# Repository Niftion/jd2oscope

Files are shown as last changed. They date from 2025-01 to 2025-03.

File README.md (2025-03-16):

## Project Status

- `3dmodels/`: Iteration 1 complete; iteration 2 WIP
  - Considering different potentiometer & button models (pot.s too small for knobs)
  - Looking into overhead enclosure for button/knob interface (i.e., transitioning from partially exposed to fully enclosed)
- `firmware/`: Iteration 1 WIP
  - Currently troubleshooting issues with SPI comm.; assumed resolution w/ the inclusion of tri-state buffer
  - Potentiometers laggy; assumed resolution w/ swap for rotary encoders
- `hardware/`: Iteration 1 complete; iteration 2 WIP
  - Adjustments needed to account for pullups/pulldowns & tri-state buffer
  - Considering swapping potentiometers for rotary encoders & using different buttons
  - Potentially re-evaluate netclasses/copper trace thicknesses
  - Flip around opAmp (for some reason was inverted in schematics)
  - Ensure all passives' values *actually exist* (if not, modify circuit to use ones that do)
  - Swap 5V LDO to buck converter (& generally re-evaluate power distribution method (currently not adequate for long-term usage))

## Project Leads

- `3dmodels/`: [@kaylauyema](https://github.com/kaylauyema)
  - *See [Onshape](https://cad.onshape.com/documents/8ccdb21e8d1079c729b3d0f6/w/fb9eb84c8df37a115b39a8e3/e/654db45d68c6c467c0a4227c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) for all CAD files*
- `firmware/`: [@StPelican42](https://github.com/StPelican42)
- `hardware/`: [@Niftion](https://github.com/Niftion)

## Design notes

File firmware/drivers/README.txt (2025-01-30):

ESP32 Windows Driver (may have different names),
 - Plug in ESP32 via cable
 - Go to Device Manager
 - Expand Ports and open properties of the device USB to UART Bridge
 - Click the Driver tab and update driver with the CP210x_Universal_Windows_Driver folder

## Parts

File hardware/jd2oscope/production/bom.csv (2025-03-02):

Designator | Footprint | Quantity | Value | LCSC Part #
C1, C10, C11, C12, C13, C14, C16, C17, C18, C19, C2, C3, C4, C6, C8 | 0603 | 15 | 0.1u
C15, C9 | 0603 | 2 | 2.7n
C5, C7 | 0603 | 2 | 10u
D1 | D_SOD-123 | 1 | SS14 | SS14
D2 | 0805 | 1 | LTST-C170CKT | LTST-C170KFKT
J1 | TerminalBlock_RND_205-00001_1x02_P5.00mm_Horizontal | 1 | 9V_CONN
J2, J3 | LINX_CONBNC001 | 2 | CONBNC001
R1 | 0603 | 1 | 100
R10, R11, R12, R13, R14, R15, R3, R4, R5, R6, R7, R8 | 0603 | 12 | 1k
R16, R9 | 0603 | 2 | 117
R2 | 0603 | 1 | 560
S1 | SW_JS202011SCQN | 1 | JS202011SCQN
S2, S3, S4 | SW_KMR731NGLFS | 3 | KMR731NGLFS
U1 | MODULE_ESP32-DEVKITC-32D | 1 | ESP32-DEVKITC-32D
U2 | PinHeader_1x14_P2.54mm_Vertical | 1 | ILI9341-320x240-TFT-Touch
U3 | SOT-223-3_TabPin2 | 1 | NCP1117-5.0_SOT223
U4, U6 | SOT95P280X145-5N | 2 | OPA192IDBVR
U5, U7 | LFCSP-16-1EP_4x4mm_P0.65mm_EP2.6x2.6mm | 2 | ADS7279IPW
VR1, VR2, VR3, VR4, VR5, VR6 | TRIM_3362P-1-103LF | 6 | 3362P-1-103LF

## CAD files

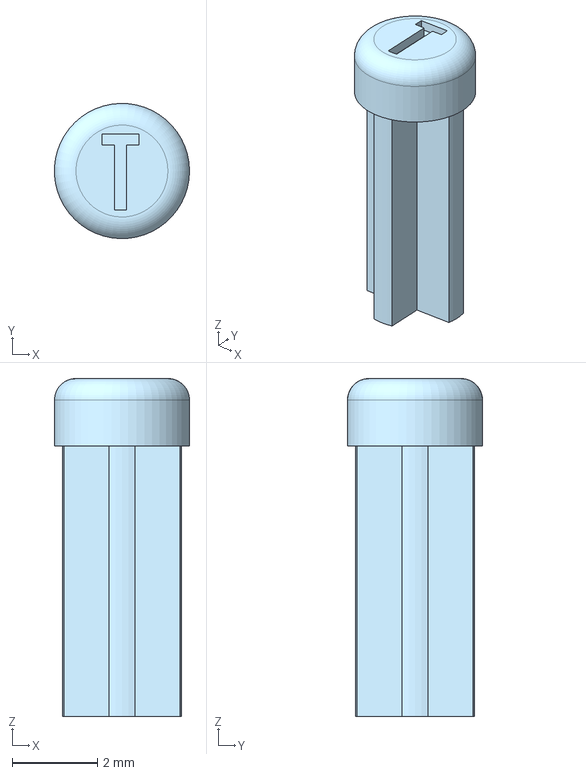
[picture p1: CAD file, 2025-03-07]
3dmodels/PotKnob_T-3x.step
3.17 x 3.17 x 7.94 mm

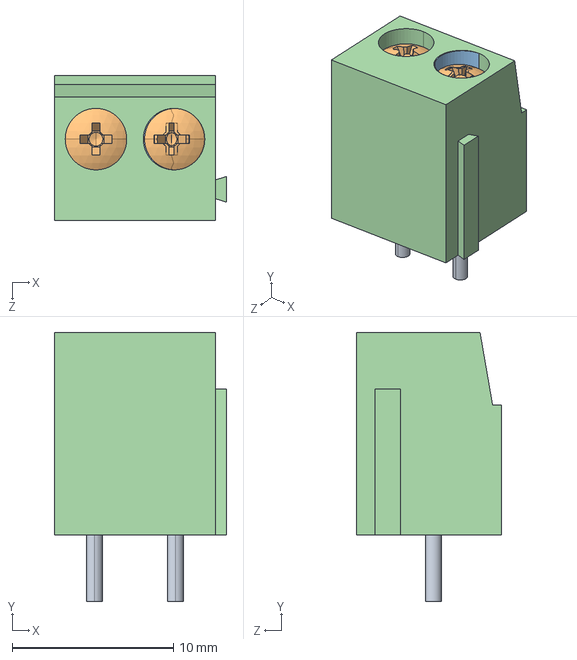
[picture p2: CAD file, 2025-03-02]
hardware/3dModels/RND 205-00001--3DModel-STEP-269445.STEP
10.7 x 16.7 x 9.02 mm

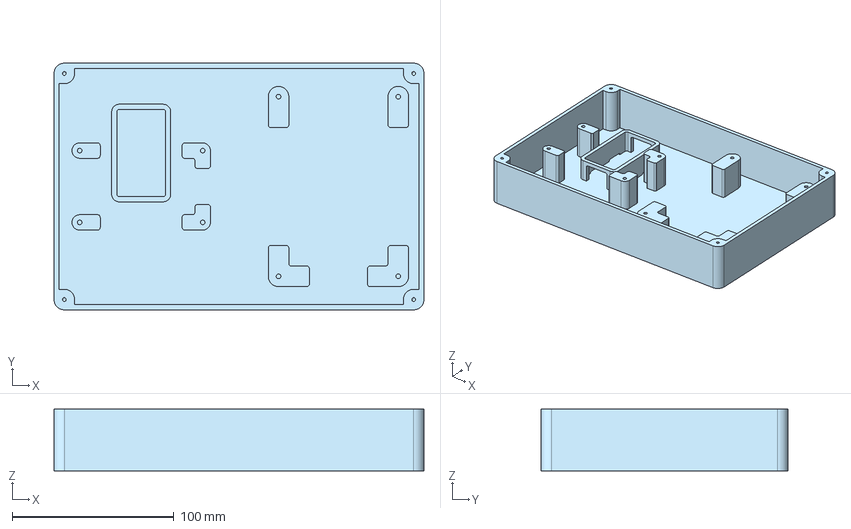
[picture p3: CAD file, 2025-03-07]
3dmodels/enclosure_bottom.step
228.6 x 152.4 x 38.1 mm

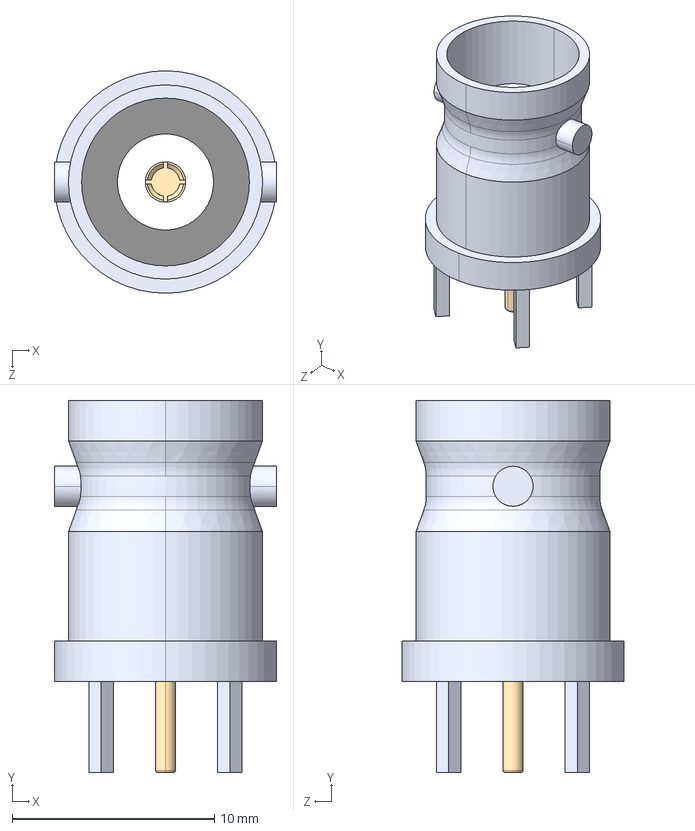
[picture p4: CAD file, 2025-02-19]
hardware/3dModels/CONBNC001.step
11.0 x 18.4 x 11.0 mm

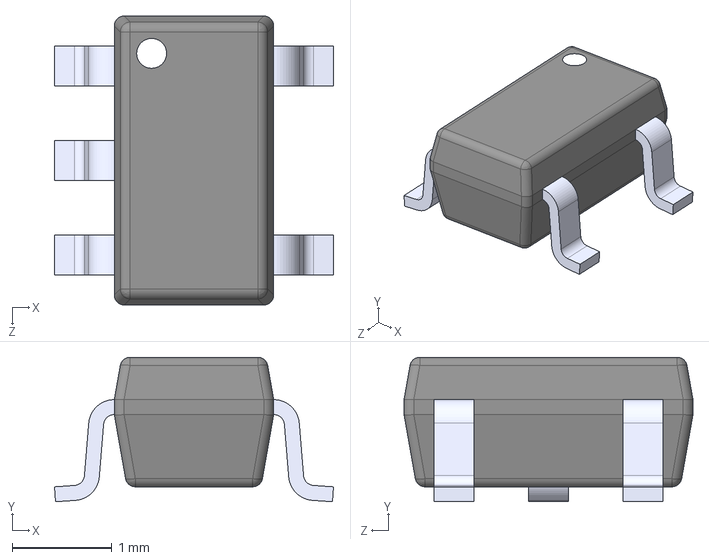
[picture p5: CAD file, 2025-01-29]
hardware/3dModels/OPA192IDBVR.STEP
2.80 x 1.45 x 2.90 mm

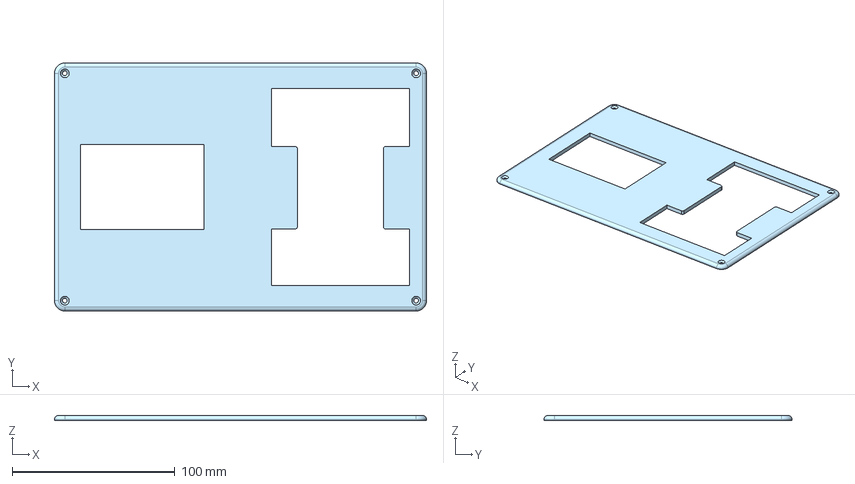
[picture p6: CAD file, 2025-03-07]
3dmodels/enclosure_top.step
228.6 x 152.4 x 3.18 mm

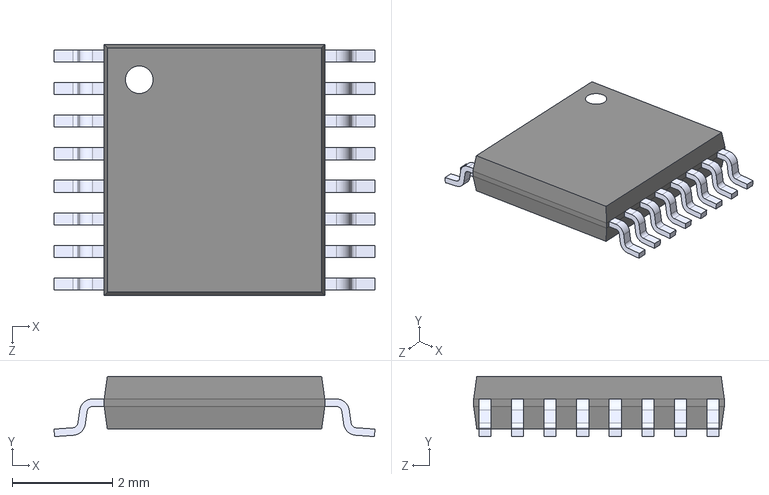
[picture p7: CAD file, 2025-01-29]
hardware/3dModels/ADS7279IPW.STEP
6.40 x 1.20 x 5.00 mm

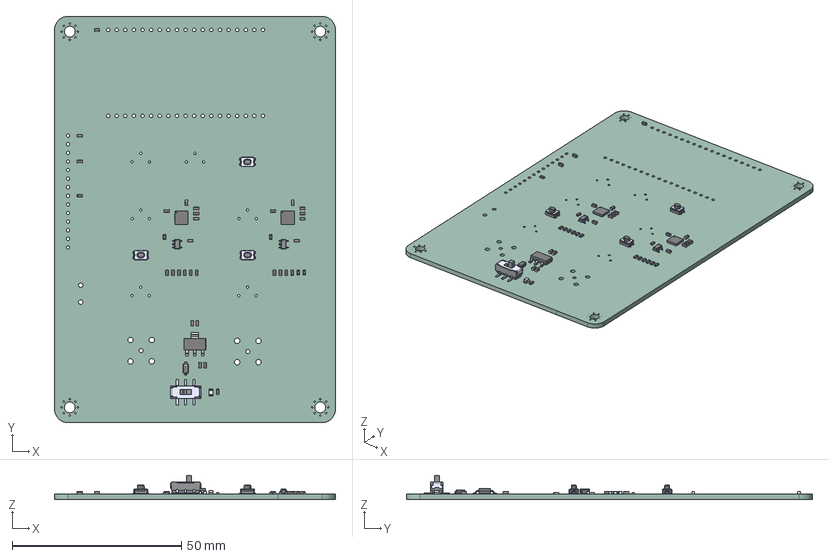
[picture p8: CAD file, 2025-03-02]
3dmodels/PCB_onlySMDs-noTracks.step
83.0 x 120.0 x 7.16 mm
R_0603_1608Metric x 16
C_0603_1608Metric x 19
CQ assembly x 2
D_SOD_123
LED_0805_2012Metric
JS202011SCQN
SOT_223
KMR731NGLFS x 3
DBV5 x 2
jd2oscope_PCB

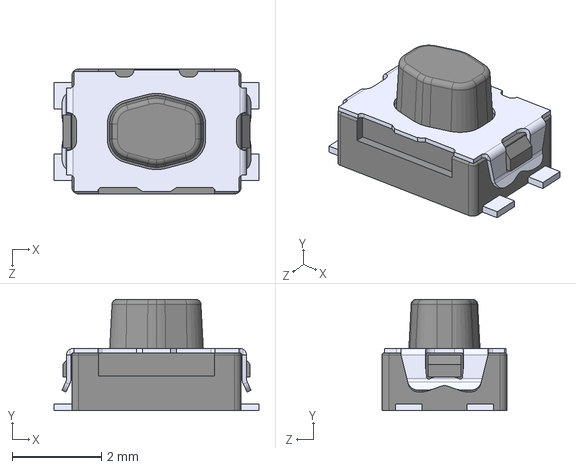
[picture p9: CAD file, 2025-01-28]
hardware/3dModels/KMR731NGLFS.step
4.60 x 2.50 x 2.80 mm

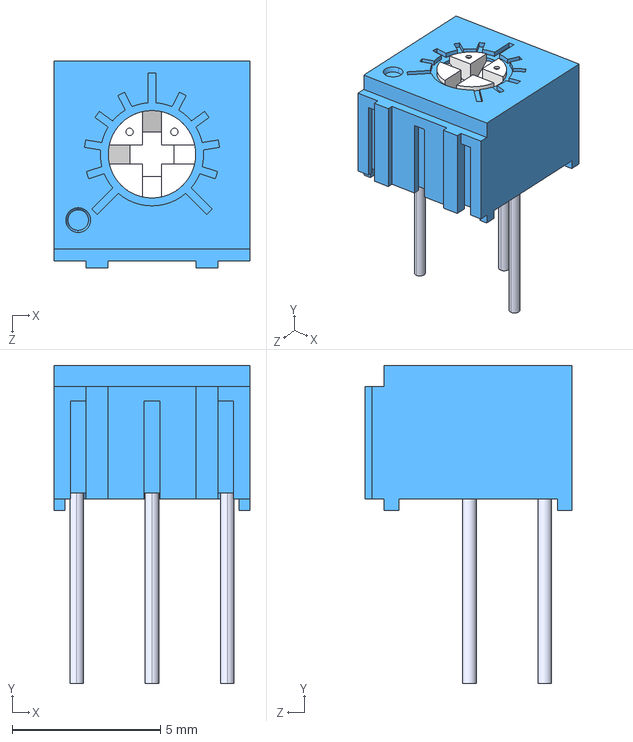
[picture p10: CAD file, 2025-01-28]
hardware/3dModels/3362P-1-103LF.step
6.60 x 10.7 x 6.99 mm

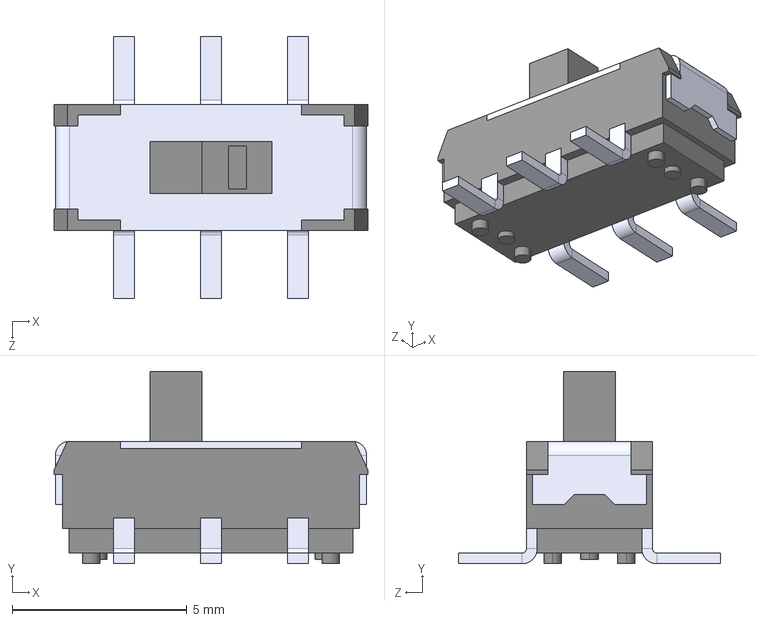
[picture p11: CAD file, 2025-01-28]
hardware/3dModels/JS202011SCQN.step
8.99 x 5.51 x 7.49 mm

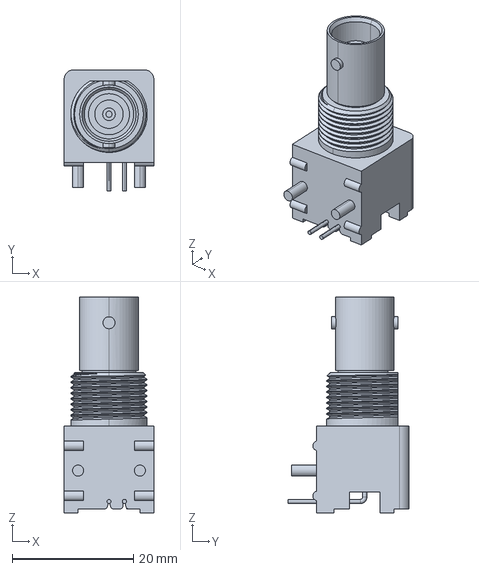
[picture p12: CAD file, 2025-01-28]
hardware/3dModels/5227161-2.step
14.8 x 20.0 x 35.6 mm

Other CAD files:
3dmodels/PotKnob_V-3x.step

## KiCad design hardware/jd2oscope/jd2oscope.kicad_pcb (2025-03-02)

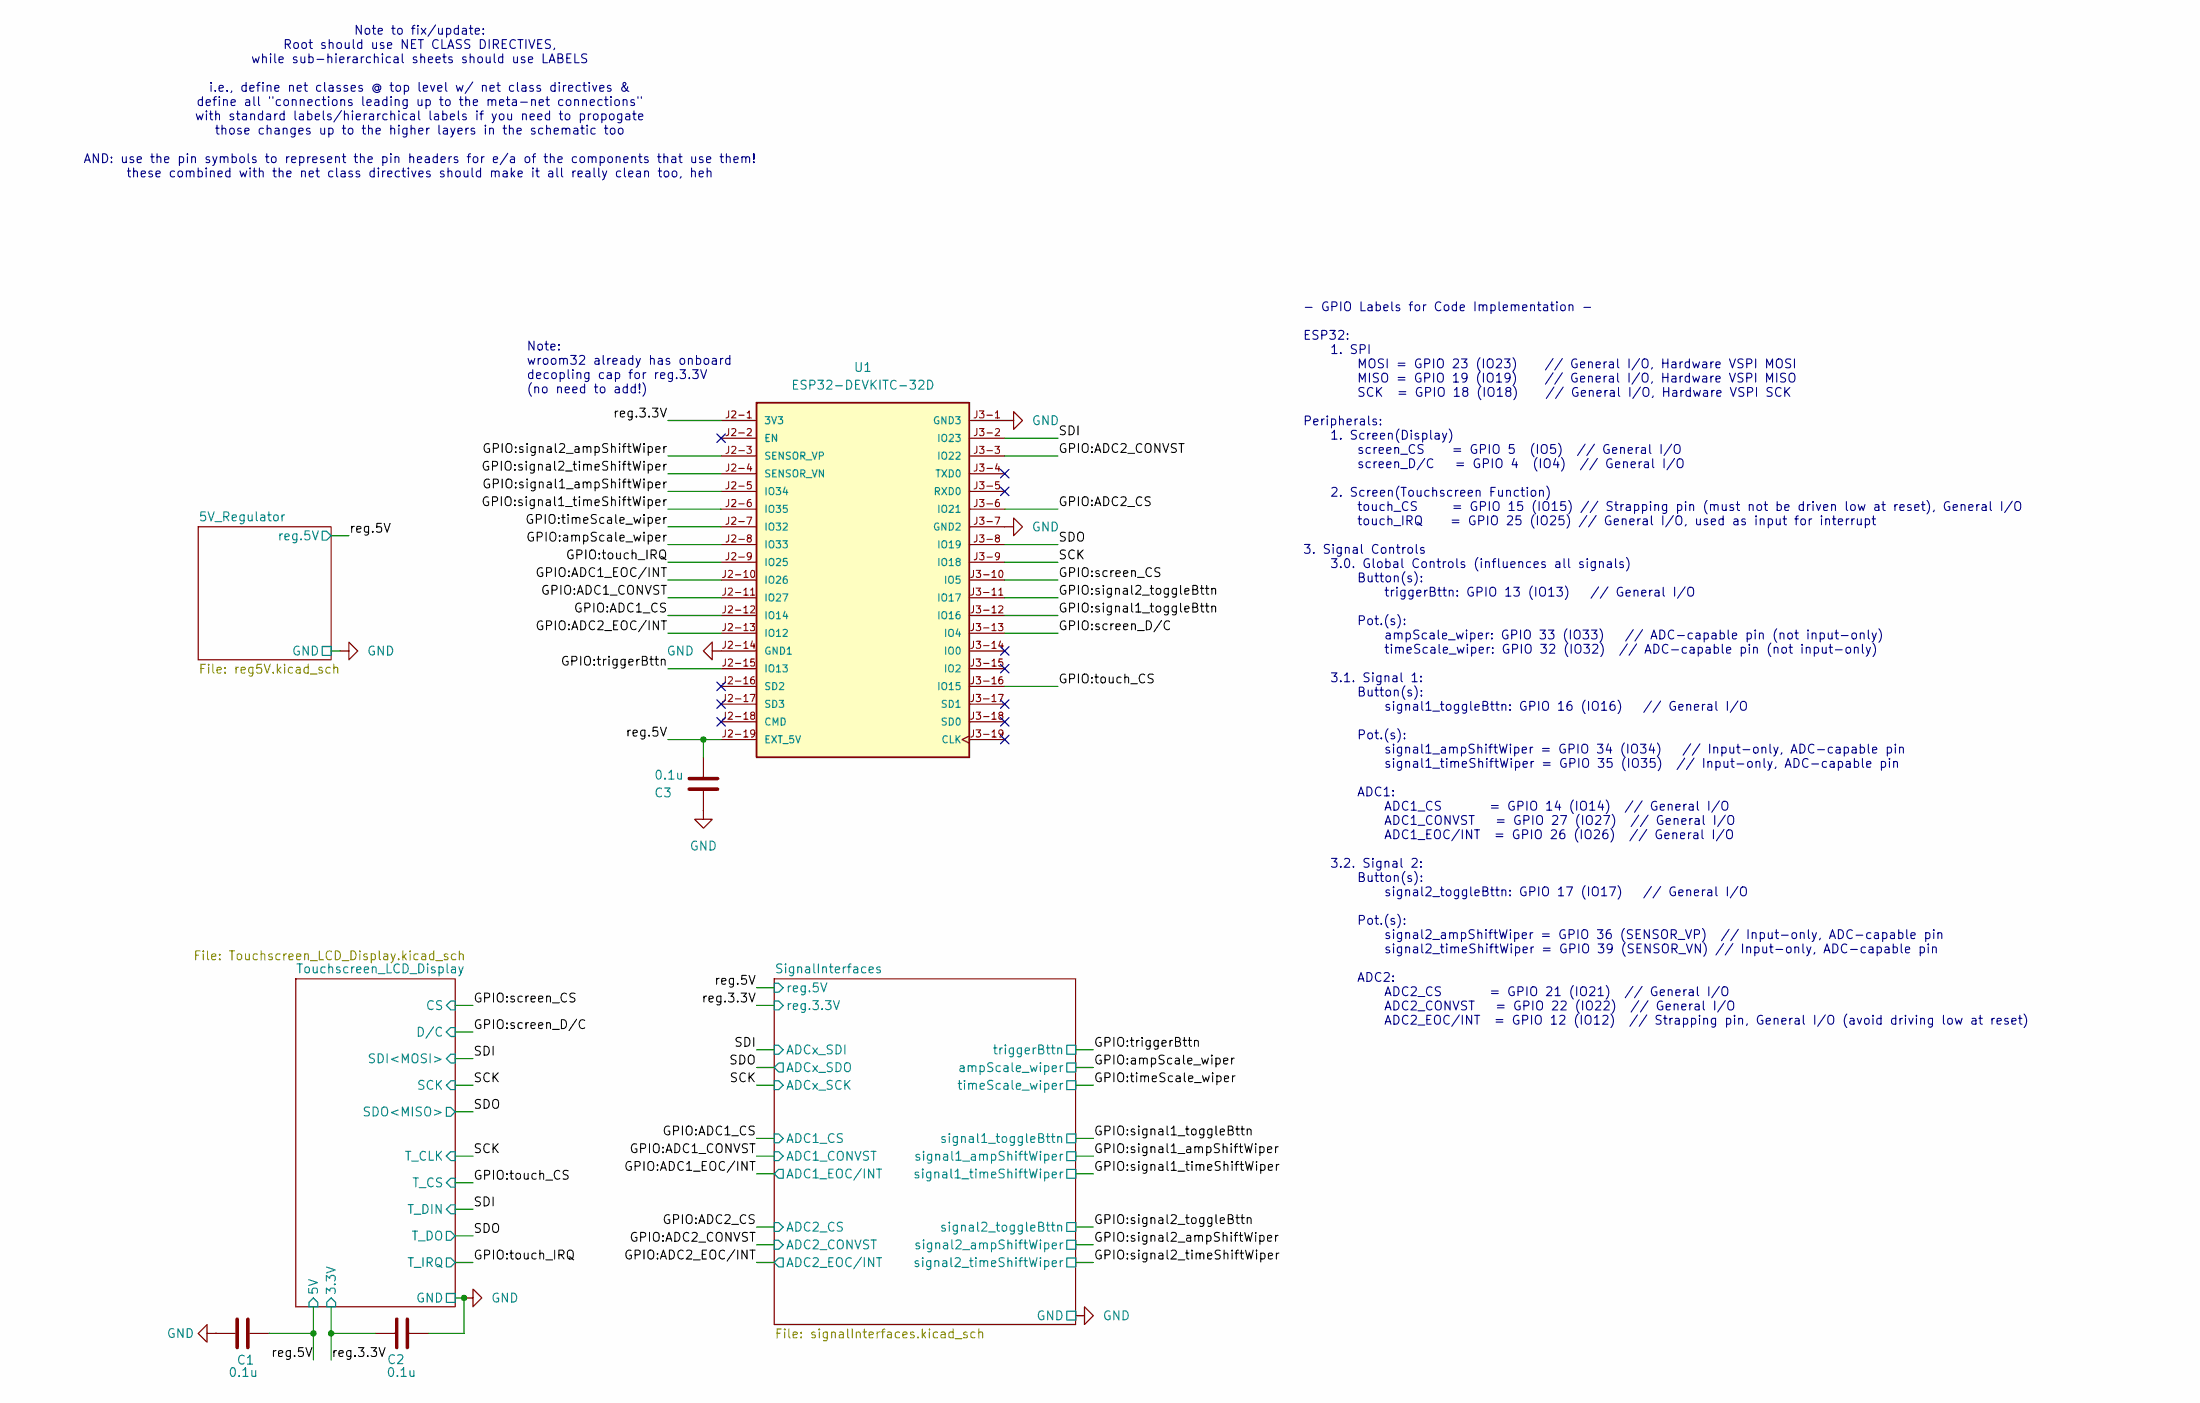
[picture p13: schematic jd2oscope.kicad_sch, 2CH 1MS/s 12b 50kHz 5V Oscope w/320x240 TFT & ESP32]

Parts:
C1, C2, C3: 0.1u; C_0603_1608Metric_Pad1.08x0.95mm_HandSolder
U1: ESP32-DEVKITC-32D; MODULE_ESP32-DEVKITC-32D; PARTREV V4; DigiKey_Part_Number 4166-ESP32-DEVKITC-32D-ND

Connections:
/GPIO:ADC1_CONVST: U1.J2-11 (IO27); also elsewhere on the board
/GPIO:ADC1_CS: U1.J2-12 (IO14); also elsewhere on the board
/GPIO:ADC1_EOC/INT: U1.J2-10 (IO26); also elsewhere on the board
/GPIO:ADC2_CONVST: U1.J3-3 (IO22); also elsewhere on the board
/GPIO:ADC2_CS: U1.J3-6 (IO21); also elsewhere on the board
/GPIO:ADC2_EOC/INT: U1.J2-13 (IO12); also elsewhere on the board
/GPIO:ampScale_wiper: U1.J2-8 (IO33); also elsewhere on the board
/GPIO:screen_CS: U1.J3-10 (IO5); also elsewhere on the board
/GPIO:screen_D/C: U1.J3-13 (IO4); also elsewhere on the board
/GPIO:signal1_ampShiftWiper: U1.J2-5 (IO34); also elsewhere on the board
/GPIO:signal1_timeShiftWiper: U1.J2-6 (IO35); also elsewhere on the board
/GPIO:signal1_toggleBttn: U1.J3-12 (IO16); also elsewhere on the board
/GPIO:signal2_ampShiftWiper: U1.J2-3 (SENSOR_VP); also elsewhere on the board
/GPIO:signal2_timeShiftWiper: U1.J2-4 (SENSOR_VN); also elsewhere on the board
/GPIO:signal2_toggleBttn: U1.J3-11 (IO17); also elsewhere on the board
/GPIO:timeScale_wiper: U1.J2-7 (IO32); also elsewhere on the board
/GPIO:touch_CS: U1.J3-16 (IO15); also elsewhere on the board
/GPIO:touch_IRQ: U1.J2-9 (IO25); also elsewhere on the board
/GPIO:triggerBttn: U1.J2-15 (IO13); also elsewhere on the board
/SCK: U1.J3-9 (IO18); also elsewhere on the board
/SDI: U1.J3-2 (IO23); also elsewhere on the board
/SDO: U1.J3-8 (IO19); also elsewhere on the board
/reg.3.3V: C2.2, U1.J2-1 (3V3); also elsewhere on the board
/reg.5V: C1.2, C3.2, U1.J2-19 (EXT_5V); also elsewhere on the board
GND: C1.1, C2.1, C3.1, U1.J2-14 (GND1), U1.J3-1 (GND3), U1.J3-7 (GND2); also elsewhere on the board

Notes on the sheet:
Note to fix/update: Root should use NET CLASS DIRECTIVES, while sub-hierarchical sheets should use LABELS i.e., define net classes @ top level w/ net class directives & define all "connections leading up to the meta-net connections" with standard labels/hierarchical labels if you need to propogate 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
- GPIO Labels for Code Implementation - ESP32: 1. SPI MOSI = GPIO 23 (IO23) // General I/O, Hardware VSPI MOSI MISO = GPIO 19 (IO19) // General I/O, Hardware VSPI MISO SCK = GPIO 18 (IO18) // General I/O, Hardware VSPI SCK Peripherals: 1. Screen(Display) screen_CS = GPIO 5 (IO5) // General I/O scre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
Note: wroom32 already has onboard decopling cap for reg.3.3V (no need to add!)

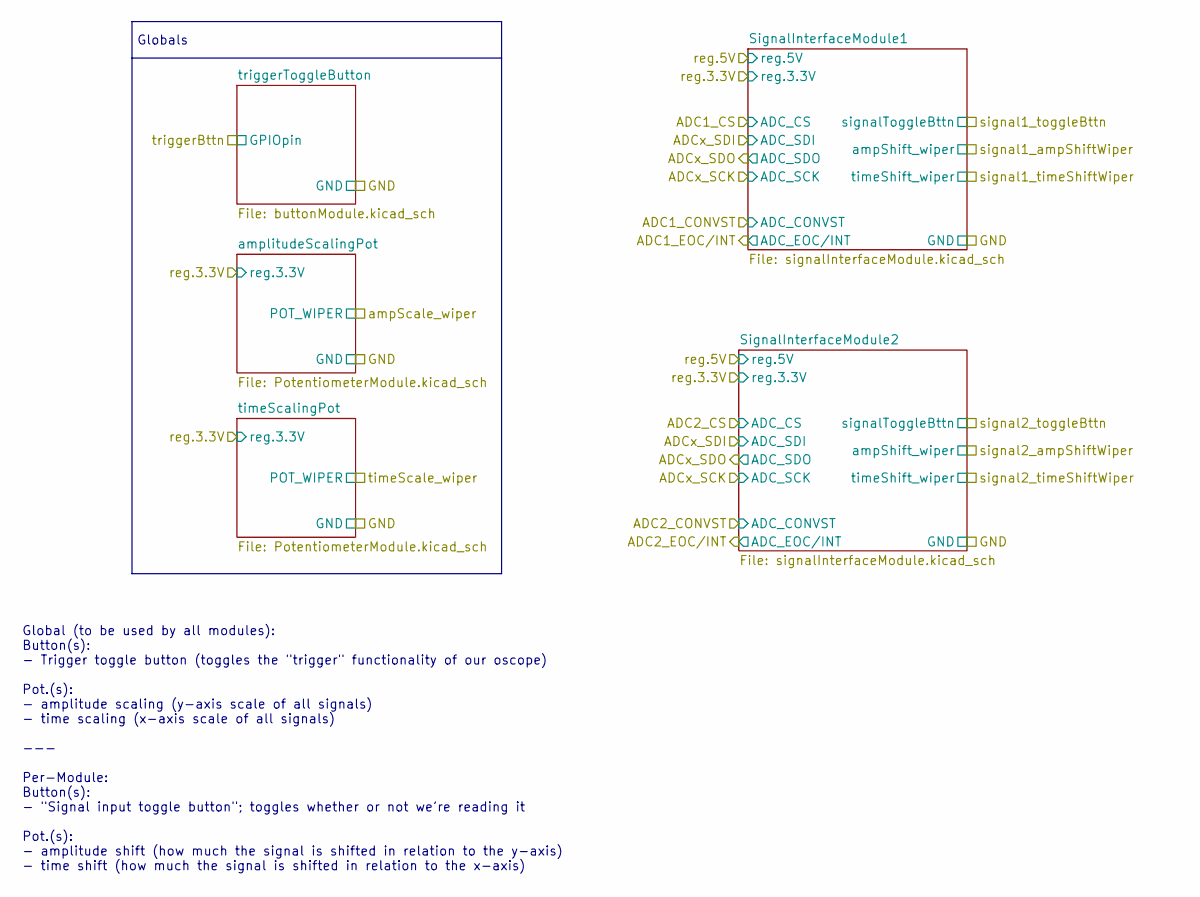
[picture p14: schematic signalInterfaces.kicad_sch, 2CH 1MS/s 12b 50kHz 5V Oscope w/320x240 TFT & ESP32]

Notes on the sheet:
Globals
Global (to be used by all modules): Button(s): - Trigger toggle button (toggles the "trigger" functionality of our oscope) Pot.(s): - amplitude scaling (y-axis scale of all signals) - time scaling (x-axis scale of all signals) --- Per-Module: Button(s): - "Signal input toggle button"; toggles wheth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

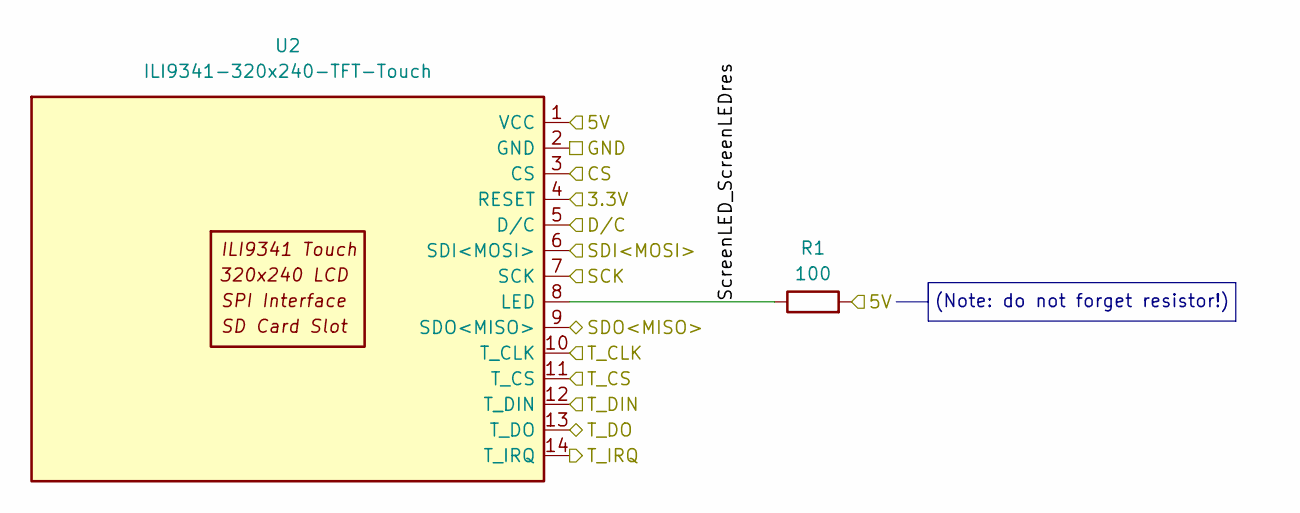
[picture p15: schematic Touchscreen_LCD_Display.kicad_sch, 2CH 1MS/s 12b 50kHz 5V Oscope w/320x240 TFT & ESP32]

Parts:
R1: 100; R_0603_1608Metric_Pad0.98x0.95mm_HandSolder
U2: ILI9341-320x240-TFT-Touch; PinHeader_1x14_P2.54mm_Vertical

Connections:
/GPIO:screen_CS: U2.3 (CS); also elsewhere on the board
/GPIO:screen_D/C: U2.5 (D/C); also elsewhere on the board
/GPIO:touch_CS: U2.11 (T_CS); also elsewhere on the board
/GPIO:touch_IRQ: U2.14 (T_IRQ); also elsewhere on the board
/SCK: U2.7 (SCK), U2.10 (T_CLK); also elsewhere on the board
/SDI: U2.6 (SDI<MOSI>), U2.12 (T_DIN); also elsewhere on the board
/SDO: U2.9 (SDO<MISO>), U2.13 (T_DO); also elsewhere on the board
/Touchscreen_LCD_Display/ScreenLED_ScreenLEDres: R1.1, U2.8 (LED)
/reg.3.3V: U2.4 (RESET); also elsewhere on the board
/reg.5V: R1.2, U2.1 (VCC); also elsewhere on the board
GND: U2.2 (GND); also elsewhere on the board

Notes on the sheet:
(Note: do not forget resistor!)

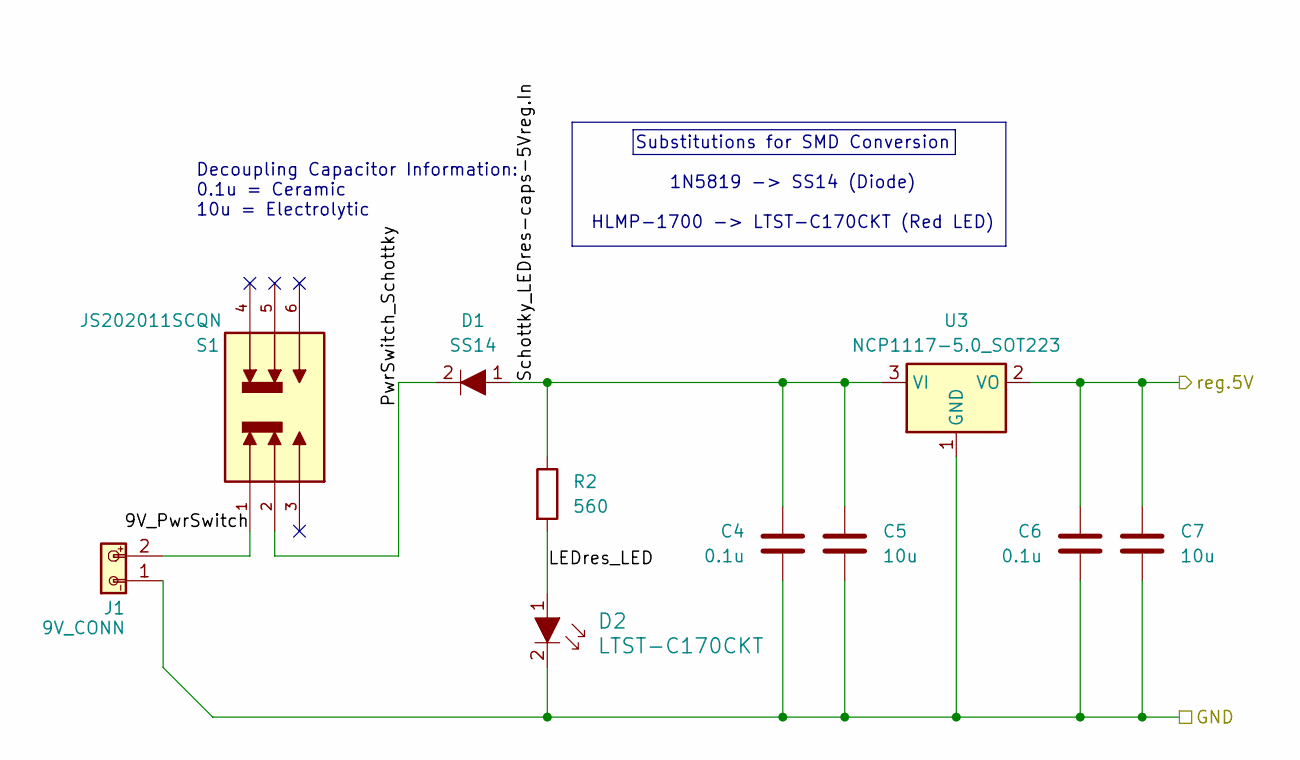
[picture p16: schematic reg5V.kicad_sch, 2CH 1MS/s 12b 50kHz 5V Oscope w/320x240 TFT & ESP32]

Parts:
C4, C6: 0.1u; C_0603_1608Metric_Pad1.08x0.95mm_HandSolder
C5, C7: 10u; C_0603_1608Metric_Pad1.08x0.95mm_HandSolder
D1: SS14; D_SOD-123; MPN SS14; Digi-Key_PN SS14CT-ND
D2: LTST-C170CKT; LED_0805_2012Metric; MPN LTST-C170KFKT; Digi-Key_PN 160-1184-1-ND
J1: 9V_CONN; TerminalBlock_RND_205-00001_1x02_P5.00mm_Horizontal
R2: 560; R_0603_1608Metric_Pad0.98x0.95mm_HandSolder
S1: JS202011SCQN; SW_JS202011SCQN; PARTREV 26 May 22
U3: NCP1117-5.0_SOT223; SOT-223-3_TabPin2

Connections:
/5V_Regulator/9V_PwrSwitch: J1.2, S1.1
/5V_Regulator/LEDres_LED: D2.1, R2.2
/5V_Regulator/PwrSwitch_Schottky: D1.2, S1.2
/5V_Regulator/Schottky_LEDres-caps-5Vreg.In: C4.2, C5.1, D1.1, R2.1, U3.3 (VI)
/reg.5V: C6.2, C7.1, U3.2 (VO); also elsewhere on the board
GND: C4.1, C5.2, C6.1, C7.2, D2.2, J1.1, U3.1 (GND); also elsewhere on the board

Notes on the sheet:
Substitutions for SMD Conversion 1N5819 -> SS14 (Diode) HLMP-1700 -> LTST-C170CKT (Red LED)
Decoupling Capacitor Information: 0.1u = Ceramic 10u = Electrolytic

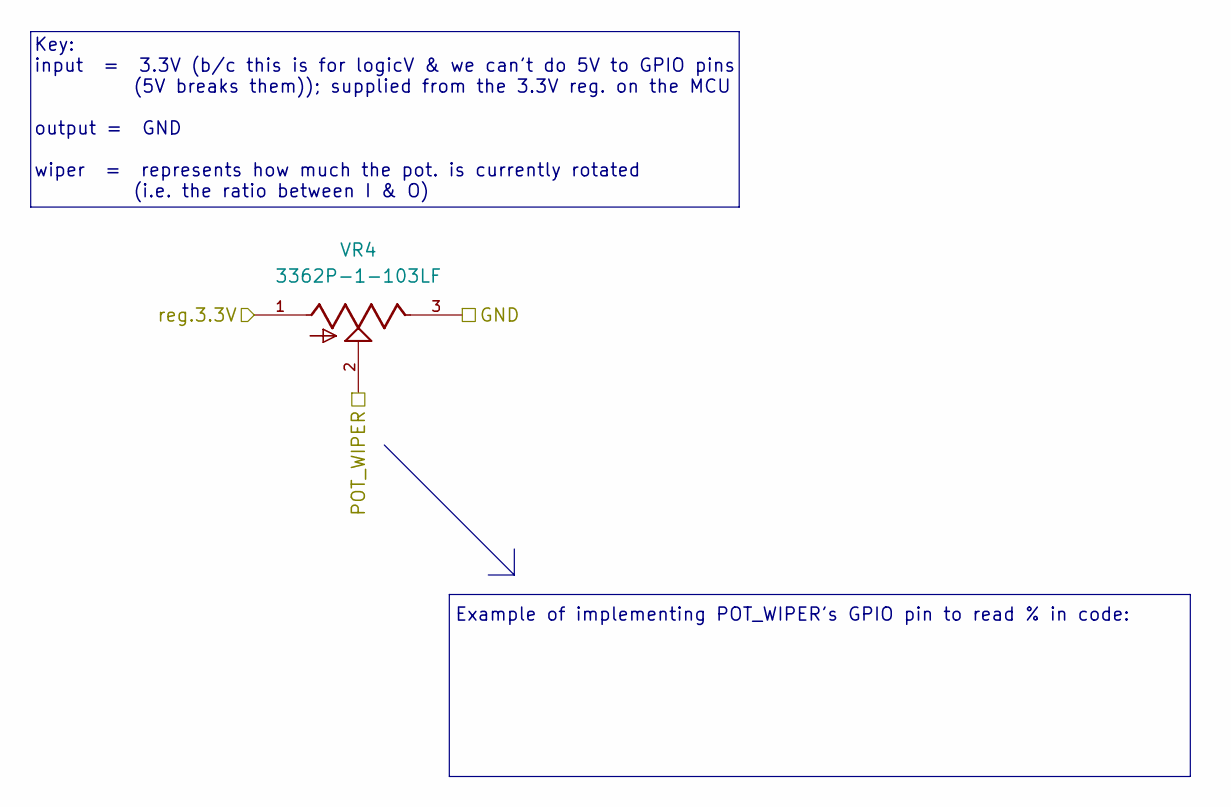
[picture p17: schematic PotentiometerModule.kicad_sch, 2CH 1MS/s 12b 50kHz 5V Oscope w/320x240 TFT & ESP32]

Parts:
VR4: 3362P-1-103LF; TRIM_3362P-1-103LF; PARTREV 08/26/10

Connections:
/GPIO:timeScale_wiper: VR4.2; also elsewhere on the board
/reg.3.3V: VR4.1; also elsewhere on the board
GND: VR4.3; also elsewhere on the board

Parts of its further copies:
VR1, VR2, VR3, VR5, VR6: 3362P-1-103LF; TRIM_3362P-1-103LF; PARTREV 08/26/10

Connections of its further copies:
/GPIO:ampScale_wiper: VR3.2; also elsewhere on the board
/GPIO:signal1_ampShiftWiper: VR1.2; also elsewhere on the board
/GPIO:signal1_timeShiftWiper: VR2.2; also elsewhere on the board
/GPIO:signal2_ampShiftWiper: VR5.2; also elsewhere on the board
/GPIO:signal2_timeShiftWiper: VR6.2; also elsewhere on the board
/reg.3.3V: VR1.1, VR2.1, VR3.1, VR5.1, VR6.1; also elsewhere on the board
GND: VR1.3, VR2.3, VR3.3, VR5.3, VR6.3; also elsewhere on the board

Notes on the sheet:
Key: input = 3.3V (b/c this is for logicV & we can't do 5V to GPIO pins (5V breaks them)); supplied from the 3.3V reg. on the MCU output = GND wiper = represents how much the pot. is currently rotated (i.e. the ratio between I & O)
Example of implementing POT_WIPER's GPIO pin to read % in code:

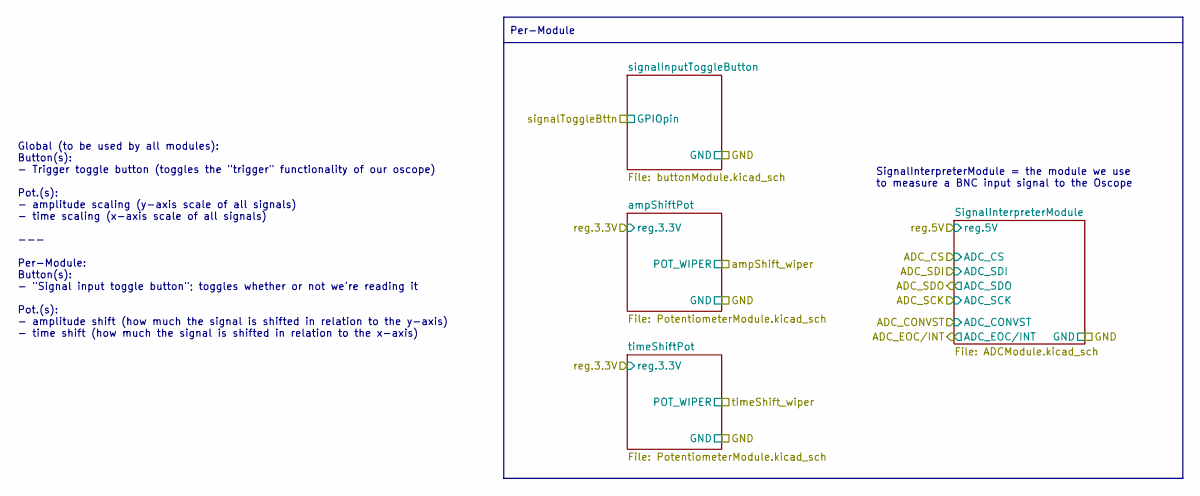
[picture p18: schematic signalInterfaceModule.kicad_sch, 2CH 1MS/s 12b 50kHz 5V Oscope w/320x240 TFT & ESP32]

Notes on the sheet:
Global (to be used by all modules): Button(s): - Trigger toggle button (toggles the "trigger" functionality of our oscope) Pot.(s): - amplitude scaling (y-axis scale of all signals) - time scaling (x-axis scale of all signals) --- Per-Module: Button(s): - "Signal input toggle button"; toggles wheth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
SignalInterpreterModule = the module we use to measure a BNC input signal to the Oscope
Per-Module

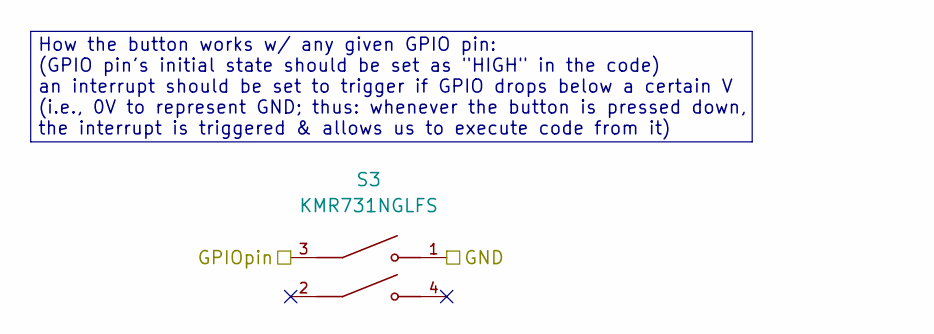
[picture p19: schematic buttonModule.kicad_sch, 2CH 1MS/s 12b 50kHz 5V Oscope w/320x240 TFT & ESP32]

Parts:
S3: KMR731NGLFS; SW_KMR731NGLFS; PARTREV N/A

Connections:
/GPIO:triggerBttn: S3.3; also elsewhere on the board
GND: S3.1; also elsewhere on the board

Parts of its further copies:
S2, S4: KMR731NGLFS; SW_KMR731NGLFS; PARTREV N/A

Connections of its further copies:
/GPIO:signal1_toggleBttn: S2.3; also elsewhere on the board
/GPIO:signal2_toggleBttn: S4.3; also elsewhere on the board
GND: S2.1, S4.1; also elsewhere on the board

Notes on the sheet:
How the button works w/ any given GPIO pin: (GPIO pin's initial state should be set as "HIGH" in the code) an interrupt should be set to trigger if GPIO drops below a certain V (i.e., 0V to represent GND; thus: whenever the button is pressed down, the interrupt is triggered & allows us to execute c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

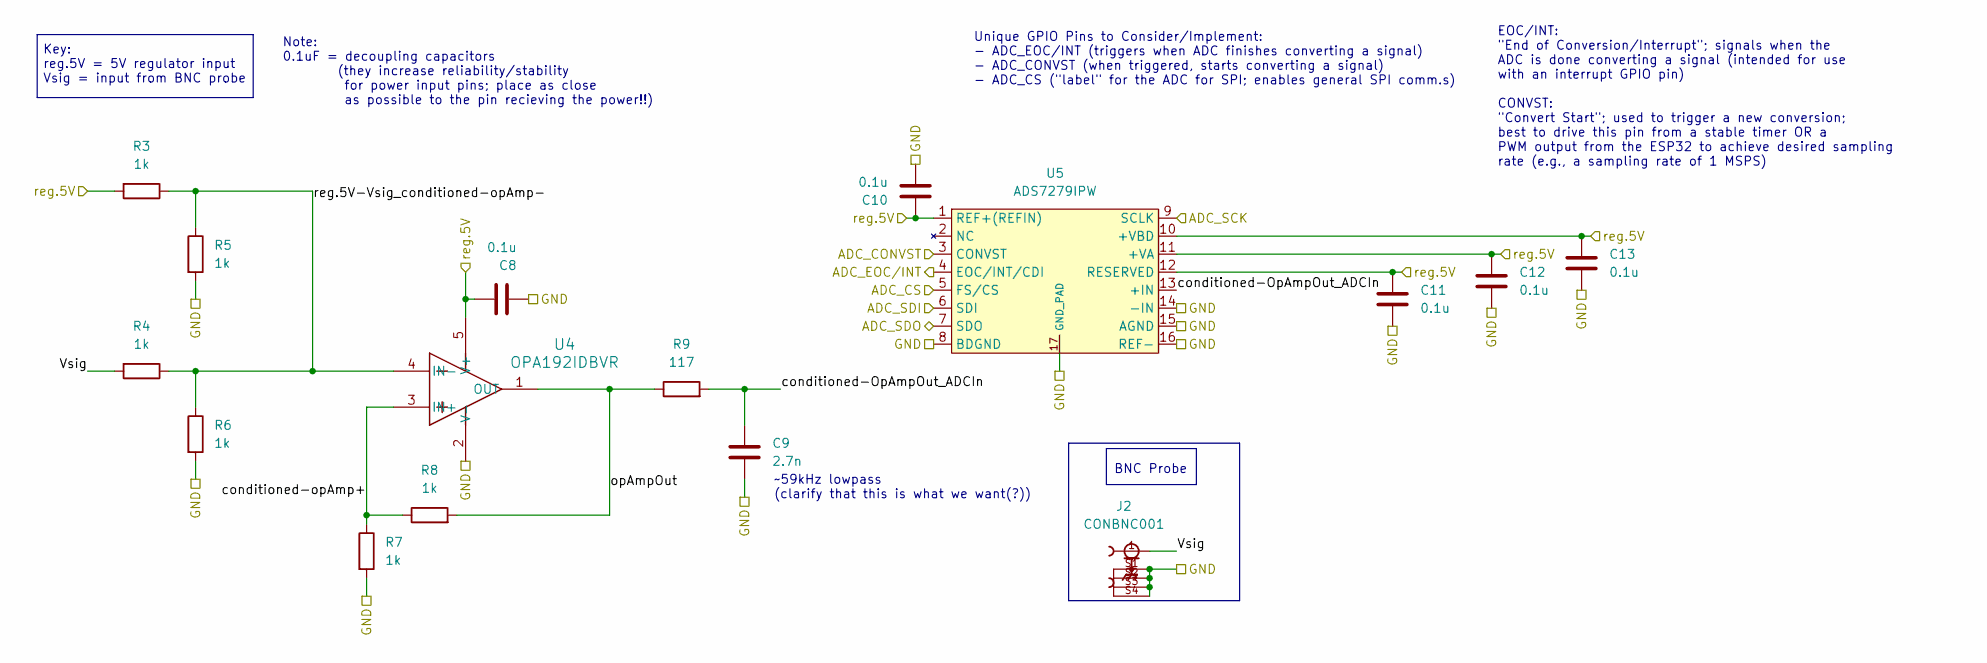
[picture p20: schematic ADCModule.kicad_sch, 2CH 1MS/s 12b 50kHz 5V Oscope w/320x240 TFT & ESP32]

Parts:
C8, C10, C11, C12, C13: 0.1u; C_0603_1608Metric_Pad1.08x0.95mm_HandSolder
C9: 2.7n; C_0603_1608Metric_Pad1.08x0.95mm_HandSolder
J2: CONBNC001; LINX_CONBNC001
R3, R4, R5, R6, R7, R8: 1k; R_0603_1608Metric_Pad0.98x0.95mm_HandSolder
R9: 117; R_0603_1608Metric_Pad0.98x0.95mm_HandSolder
U4: OPA192IDBVR; SOT95P280X145-5N
U5: ADS7279IPW; LFCSP-16-1EP_4x4mm_P0.65mm_EP2.6x2.6mm

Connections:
/GPIO:ADC1_CONVST: U5.3 (CONVST); also elsewhere on the board
/GPIO:ADC1_CS: U5.5 (FS/CS); also elsewhere on the board
/GPIO:ADC1_EOC/INT: U5.4 (EOC/INT/CDI); also elsewhere on the board
/SCK: U5.9 (SCLK); also elsewhere on the board
/SDI: U5.6 (SDI); also elsewhere on the board
/SDO: U5.7 (SDO); also elsewhere on the board
/SignalInterfaces/SignalInterfaceModule1/SignalInterpreterModule/Vsig: J2.1, R4.2
/SignalInterfaces/SignalInterfaceModule1/SignalInterpreterModule/conditioned-Op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: C9.1, R9.2, U5.13 (+IN)
/SignalInterfaces/SignalInterfaceModule1/SignalInterpreterModule/conditioned-op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: R7.1, R8.1, U4.3 (IN+)
/SignalInterfaces/SignalInterfaceModule1/SignalInterpreterModule/opAmpOut: R8.2, R9.1, U4.1 (OUT)
/SignalInterfaces/SignalInterfaceModule1/SignalInterpreterModule/reg.5V-Vsig_co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: R3.1, R4.1, R5.1, R6.1, U4.4 (IN-)
/reg.5V: C8.1, C10.1, C11.1, C12.1, C13.1, R3.2, U4.5 (V+), U5.1 (REF+(REFIN)), U5.10 (+VBD), U5.11 (+VA), U5.12 (RESERVED); also elsewhere on the board
GND: C8.2, C9.2, C10.2, C11.2, C12.2, C13.2, J2.S1, J2.S2, J2.S3, J2.S4, R5.2, R6.2, R7.2, U4.2 (V-), U5.8 (BDGND), U5.14 (-IN), U5.15 (AGND), U5.16 (REF-), U5.17 (GND_PAD); also elsewhere on the board

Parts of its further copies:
C14, C16, C17, C18, C19: 0.1u; C_0603_1608Metric_Pad1.08x0.95mm_HandSolder
C15: 2.7n; C_0603_1608Metric_Pad1.08x0.95mm_HandSolder
J3: CONBNC001; LINX_CONBNC001
R10, R11, R12, R13, R14, R15: 1k; R_0603_1608Metric_Pad0.98x0.95mm_HandSolder
R16: 117; R_0603_1608Metric_Pad0.98x0.95mm_HandSolder
U6: OPA192IDBVR; SOT95P280X145-5N
U7: ADS7279IPW; LFCSP-16-1EP_4x4mm_P0.65mm_EP2.6x2.6mm

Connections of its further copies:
/GPIO:ADC2_CONVST: U7.3 (CONVST); also elsewhere on the board
/GPIO:ADC2_CS: U7.5 (FS/CS); also elsewhere on the board
/GPIO:ADC2_EOC/INT: U7.4 (EOC/INT/CDI); also elsewhere on the board
/SCK: U7.9 (SCLK); also elsewhere on the board
/SDI: U7.6 (SDI); also elsewhere on the board
/SDO: U7.7 (SDO); also elsewhere on the board
/SignalInterfaces/SignalInterfaceModule2/SignalInterpreterModule/Vsig: J3.1, R11.2
/SignalInterfaces/SignalInterfaceModule2/SignalInterpreterModule/conditioned-Op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: C15.1, R16.2, U7.13 (+IN)
/SignalInterfaces/SignalInterfaceModule2/SignalInterpreterModule/conditioned-op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: R14.1, R15.1, U6.3 (IN+)
/SignalInterfaces/SignalInterfaceModule2/SignalInterpreterModule/opAmpOut: R15.2, R16.1, U6.1 (OUT)
/SignalInterfaces/SignalInterfaceModule2/SignalInterpreterModule/reg.5V-Vsig_co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: R10.1, R11.1, R12.1, R13.1, U6.4 (IN-)
/reg.5V: C14.1, C16.1, C17.1, C18.1, C19.1, R10.2, U6.5 (V+), U7.1 (REF+(REFIN)), U7.10 (+VBD), U7.11 (+VA), U7.12 (RESERVED); also elsewhere on the board
GND: C14.2, C15.2, C16.2, C17.2, C18.2, C19.2, J3.S1, J3.S2, J3.S3, J3.S4, R12.2, R13.2, R14.2, U6.2 (V-), U7.8 (BDGND), U7.14 (-IN), U7.15 (AGND), U7.16 (REF-), U7.17 (GND_PAD); also elsewhere on the board

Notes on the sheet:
Key: reg.5V = 5V regulator input Vsig = input from BNC probe
~59kHz lowpass (clarify that this is what we want(?))
EOC/INT: "End of Conversion/Interrupt"; signals when the ADC is done converting a signal (intended for use with an interrupt GPIO pin) CONVST: "Convert Start"; used to trigger a new conversion; best to drive this pin from a stable timer OR a PWM output from the ESP32 to achieve desired sampling rat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
Note: 0.1uF = decoupling capacitors (they increase reliability/stability for power input pins; place as close as possible to the pin recieving the power!!)
BNC Probe
Unique GPIO Pins to Consider/Implement: - ADC_EOC/INT (triggers when ADC finishes converting a signal) - ADC_CONVST (when triggered, starts converting a signal) - ADC_CS ("label" for the ADC for SPI; enables general SPI comm.s)

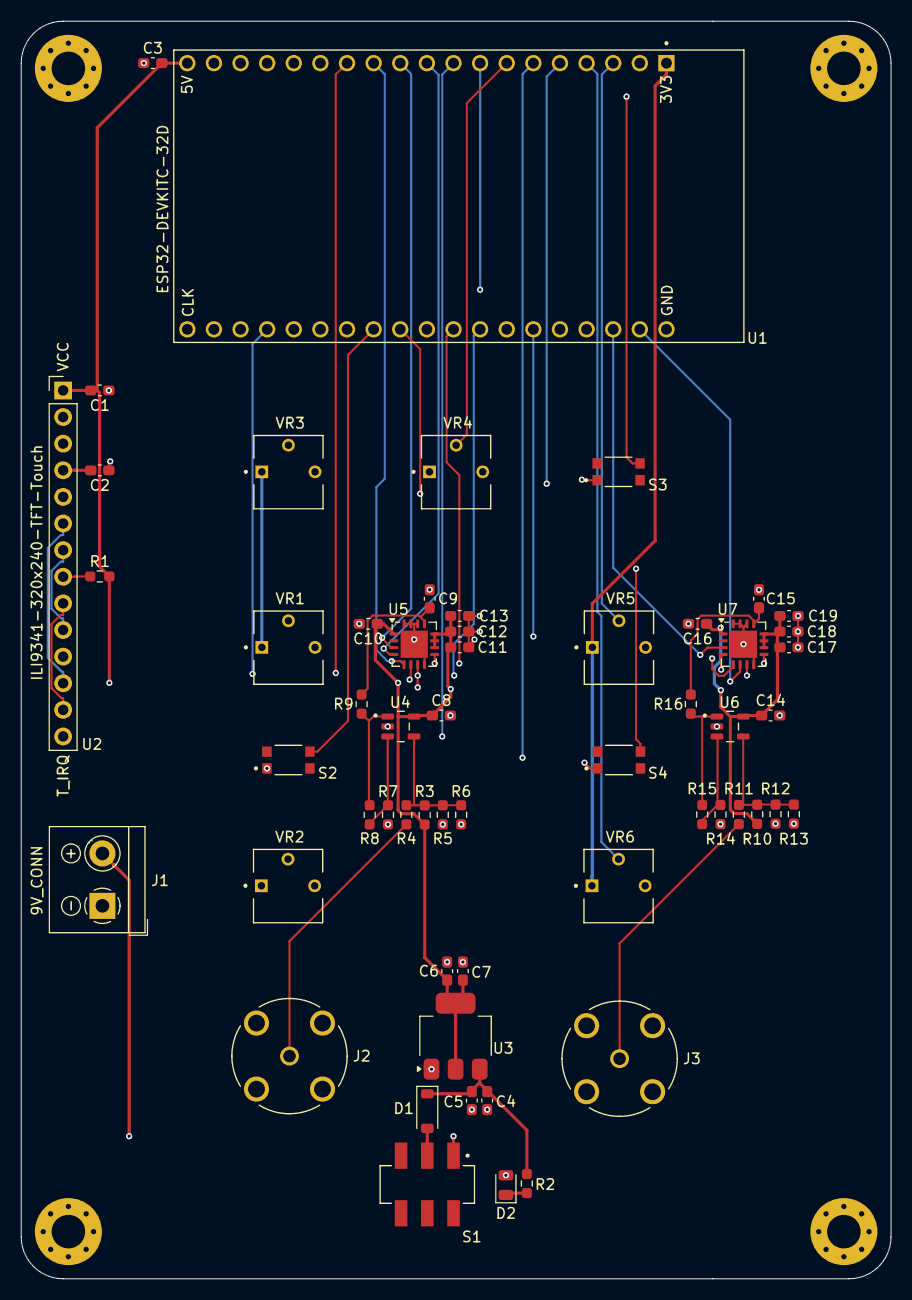
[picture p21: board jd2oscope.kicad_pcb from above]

Board: 4 copper layers, 83.0 x 120.0 mm, 61 parts (0 on the bottom side), 40 nets.

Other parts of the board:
REF1, REF2, REF3, REF4: MountingHole_3.2mm_M3_Pad_Via

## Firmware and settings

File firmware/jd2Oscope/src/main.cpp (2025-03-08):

#include <Arduino.h>
#include <stdio.h>
#include <string.h>
#include <unistd.h>
#include <esp_timer.h>
#include <esp_err.h>
#include "esp_log.h"
#include "esp_sleep.h"
#include "sdkconfig.h"
#include "SPI.h"


#include <TFT_eSPI.h>  // Bodmer's TFT_eSPI library
#include "User_Setup.h"
#include <TFT_eWidget.h>               // Widget library


TFT_eSPI tft = TFT_eSPI();




GraphWidget gr = GraphWidget(&tft);    // Graph widget gr instance with pointer to tft
TraceWidget tr1 = TraceWidget(&gr);    // Graph trace 1
TraceWidget tr2 = TraceWidget(&gr);    // Graph trace 2


//****************************************
//Variable Declarations
//****************************************


const float gxLow  = 0.0;
const float gxHigh = 100.0;
const float gyLow  = -512.0;
const float gyHigh = 512.0;
const int graph_length = 290;
const int graph_height = 190;
float graph_scale_xmin = 0.0;
float graph_scale_xmax = 100.0;
float graph_scale_ymin = -50.0;
float graph_scale_ymax = 50.0;
float graph_scale_xgrid = 10.0;
float graph_scale_ygrid = 10.0;
int graph_top_corner_x = 20;
int graph_top_corner_y = 20;


//Global Vars
int triggerBttn = 13; //GPIO 13
int SDO_pin = 19;
int SDI_pin = 23;
int ampScale_wiper = 33;
int timeScale_wiper = 32;

uint8_t ADC1_valH;
uint8_t ADC1_valL;
uint8_t ADC2_valH;
uint8_t ADC2_valL;
uint16_t ADC_14bit_val=0;

//Screen
int screen_CS = 5;
int screen_DC = 4;

//Signal 1
int signal1_toggleBttn = 16;

int signal1_ampShift_Wiper = 34;
int signal1_timeShiftWiper = 35;

int ADC1_EocInt = 26; // GPIO 26; intended for an interrupt (used to tell us when the ADC is done recording data)
int ADC1_CS_pin = 14; //  GPIO 14, Chip select pin for ADC (Slave select pin for SPI)
int ADC1_CONVST_pin = 27; //GPIO 27 (used to trigger a new conversion; best to drive it from a stable timer or a PWM output from the esp32 to achieve a desired sampling rate)
//int ADC_raw_val;

//Signal 2
int signal2_toggleBttn =  17;

int signal2_ampShiftWiper = 36;
int signal2_timeShiftWiper = 39;

int ADC2_CS_pin = 21;
int ADC2_CONVST_pin = 22;
int ADC2_EocInt = 12;


//-------------------------------
float display_data[100];
float real_data[100];
float trigger_data[200];
volatile byte pause_state = LOW;
volatile byte trigger_state = LOW;


volatile int spi_max_clk = 27000000;// Max SPI clk frequency is 27MHz.




//int ADC_val_converter(int example_input);
//static double volts_to_bits(double volt_in);
//static double bits_to_volts(double bit_in);




//*************************************************
//Function Declarations
//*************************************************


unsigned long testFillScreen();
unsigned long testText();
//unsigned long testProportionalText();
unsigned long testLines(uint16_t color);
unsigned long testFastLines(uint16_t color1, uint16_t color2);
unsigned long testRects(uint16_t color);
unsigned long testFilledRects(uint16_t color1, uint16_t color2);
unsigned long testFilledCircles(uint8_t radius, uint16_t color);
unsigned long testCircles(uint8_t radius, uint16_t color);
unsigned long testTriangles();
unsigned long testFilledTriangles();
unsigned long testRoundRects();
unsigned long testFilledRoundRects();
int findMax(float array[]);
int findMax(float array[]);
void pause_button();
void trigger_set();
void trigger_function();
void ADC_collect_data();
void ADC_Set_Default();
void pauseTFTComms();
void startTFTComms();





void setup() {


  //tft.begin();
  // Note: you can now set the SPI speed to any value
  // the default value is 30Mhz, but most ILI9341 displays
  // can handle at least 60Mhz and as much as 100Mhz
  //  tft.setClock(60000000);
    //tft.fillScreen(ILI9341_BLACK);
    //tft.setTextColor(ILI9341_YELLOW);
    //tft.setTextSize(2);
    //tft.println("Waiting for Arduino Serial Monitor...");


  //********************************************************************
  //SPI Interface Setup
  //********************************************************************
  
  //pinMode(ADC1_CS_pin, OUTPUT);
  //digitalWrite(ADC1_CS_pin, HIGH);
  //SPI.begin();
 




  //********************************************************************
  // Graph Setup
  //********************************************************************
  Serial.begin(115200);
  SPI.begin();//SCK, MISO, MOSI, CS
  delay(5000);

  pinMode(screen_CS, OUTPUT);
  digitalWrite(screen_CS, HIGH);
  tft.begin();
  
  tft.setRotation(3);
  tft.fillScreen(TFT_BLACK);
  // Graph area is 200 pixels wide, 150 high, dark grey background
  gr.createGraph(graph_length, graph_height, tft.color565(5, 5, 5));
  // x scale units is from 0 to 100, y scale units is -50 to 50
  gr.setGraphScale(graph_scale_xmin, graph_scale_xmax, graph_scale_ymin, graph_scale_ymax);
  // X grid starts at 0 with lines every 10 x-scale units
  // Y grid starts at -50 with lines every 25 y-scale units
  // blue grid
  gr.setGraphGrid(graph_scale_xmin, graph_scale_xgrid, graph_scale_ymin, graph_scale_ygrid, TFT_BLUE);
  // Draw empty graph, top left corner at 40,10 on TFT
  gr.drawGraph(graph_top_corner_x, graph_top_corner_y);
  // Start a trace with using red and another with green
  //tr1.startTrace(TFT_RED);
  //tr2.startTrace(TFT_GREEN);
  // Add points on graph to trace 1 using graph scale factors
  //tr1.addPoint(0.0, 0.0);
  //tr1.addPoint(50.0, 0.0);
  // Add points on graph to trace 2 using graph scale factors
  // Points are off graph so the plotted line is clipped to graph area
  //tr2.addPoint(0.0, -50.0);
  //tr2.addPoint(50.0, 50.0);
  // Get x,y pixel coordinates of any scaled point on graph
  // and ring that point.
  //tft.drawCircle(gr.getPointX(50.0), gr.getPointY(0.0), 5, TFT_MAGENTA);


  // Draw the x axis scale
  tft.setTextDatum(TC_DATUM); // Top centre text datum
  tft.drawNumber(int(graph_scale_xmin), gr.getPointX(graph_scale_xmin), gr.getPointY(graph_scale_ymin) + 3);
  tft.drawNumber(int(graph_scale_xmax - graph_scale_xmin), gr.getPointX(graph_scale_xmax - graph_scale_xmin), gr.getPointY(graph_scale_ymin) + 3);
  tft.drawNumber(int(graph_scale_xmax), gr.getPointX(graph_scale_xmax), gr.getPointY(graph_scale_ymin) + 3);


  // Draw the y axis scale
  tft.setTextDatum(MR_DATUM); // Middle right text datum
  tft.drawNumber(int(graph_scale_ymin), gr.getPointX(graph_scale_xmin), gr.getPointY(graph_scale_ymin));
  tft.drawNumber(int(graph_scale_ymax - graph_scale_ymin), gr.getPointX(graph_scale_xmin), gr.getPointY(graph_scale_ymax - graph_scale_ymin));
  tft.drawNumber(int(graph_scale_ymax), gr.getPointX(graph_scale_xmin), gr.getPointY(graph_scale_ymax));


  //attempt to get labels right
  tft.setRotation(2);
  tft.setCursor(100, 5);
  tft.setTextColor(ILI9341_WHITE);  tft.setTextSize(1);
  tft.println("Voltage (V)");
  tft.setRotation(3);
  tft.setCursor(150, 225);
  tft.setTextColor(ILI9341_WHITE);  tft.setTextSize(1);
  tft.println("Time (sec)");
  tft.setCursor(150, 5);
  tft.setTextColor(ILI9341_WHITE);  tft.setTextSize(1);
  tft.println("Trigger: Falling");
  tft.setCursor(50, 5);
  tft.setTextColor(ILI9341_WHITE);  tft.setTextSize(1);
  tft.println("Amplitude: ");
  tft.setCursor(275, 5);
  tft.setTextColor(ILI9341_YELLOW);  tft.setTextSize(1);
  tft.println("CH1");
  tft.setCursor(300, 5);
  tft.setTextColor(ILI9341_GREEN);  tft.setTextSize(1);
  tft.println("CH2");
 


  // Restart traces with new colours
  tr1.startTrace(TFT_WHITE);
  tr2.startTrace(TFT_YELLOW);


  
 


  //++++++++++++Interrupts for Pausing, Trigger, and Channel Select
  //int pause_pin
  //int trigger_pin
  //int Ch1_pin
  //int Ch2_pin
  pinMode(signal1_toggleBttn, INPUT_PULLUP);// Using GPIO 6 for button testing
  pinMode(triggerBttn, INPUT_PULLUP);
  pinMode(ADC1_CS_pin, OUTPUT);
  pinMode(ADC1_EocInt, INPUT_PULLUP);
  pinMode(ADC1_CONVST_pin, OUTPUT);
  //attachInterrupt(digitalPinToInterrupt(26), trigger_set, FALLING); //was pause_button, now trigger_state
  attachInterrupt(digitalPinToInterrupt(signal1_toggleBttn), pause_button, FALLING);
  attachInterrupt(digitalPinToInterrupt(triggerBttn), trigger_set, FALLING);
  attachInterrupt(digitalPinToInterrupt(ADC1_EocInt), ADC_collect_data, FALLING);

  //Set ADC to default mode and start converting values


  ADC_Set_Default();
}


void loop() {
  startTFTComms();
 
  while(!pause_state){
    delayMicroseconds(10);
    tft.fillRect(150, 5, 100, 10, TFT_BLACK);
    tft.setCursor(150, 5);
    tft.setTextColor(ILI9341_WHITE);  tft.setTextSize(1);


    if(!trigger_state){
      delayMicroseconds(1);
      tft.println(ADC_14bit_val);
      //tft.println("Trigger: Rising");
    }else{
      delayMicroseconds(1);
      //tft.println("Trigger: Falling");
      tft.println(ADC_14bit_val);
    }
  trigger_function();
  static uint32_t plotTime = micros(); // used to be = millis(), now using micros
  int Amplitude = (findMax(real_data) - findMin(real_data))/2;
  tft.setCursor(110, 5);
  tft.fillRect(110, 5, 10, 10, TFT_BLACK);
  tft.setTextColor(ILI9341_WHITE);  tft.setTextSize(1);
  tft.println(Amplitude);
  int y_zoom = analogRead(ampScale_wiper) + 1; // GPIO 34
  int x_zoom = analogRead(timeScale_wiper) + 1;
  //int val = -1;//analogRead(ADC_out_pin); //fix this when SPI gets updated
  static float gx = 0.0, gy = 0.0;
  //static float delta = 7.0;
  int SampleTime = 4095/(x_zoom);
  
  if ((x_zoom > analogRead(timeScale_wiper)+40) || (x_zoom < analogRead(timeScale_wiper)-40)){
    //Time (x) axis zoom
    tft.fillRect(0, gr.getPointY(graph_scale_ymin) + 3, 320, 10, TFT_BLACK);
    tft.setTextColor(ILI9341_WHITE);
    tft.setTextDatum(TC_DATUM); // Top centre text datum
    tft.drawNumber(0, gr.getPointX(graph_scale_xmin), gr.getPointY(graph_scale_ymin) + 3);
    tft.drawNumber((409.5/(.2*x_zoom)), gr.getPointX(graph_scale_xmax - graph_scale_xmin), gr.getPointY(graph_scale_ymin) + 3);
    tft.drawNumber((409.5/(.1*x_zoom)), gr.getPointX(graph_scale_xmax), gr.getPointY(graph_scale_ymin) + 3);
  }

  if ((y_zoom > analogRead(ampScale_wiper)+40) || (y_zoom < analogRead(ampScale_wiper)-40)){
    //voltage (y) axis zoom
    tft.fillRect(0, 0, 19, 220, TFT_BLACK);
    tft.setRotation(2);
    tft.setCursor(100, 5);
    tft.setTextColor(ILI9341_WHITE);  tft.setTextSize(1);
    tft.println("Voltage (V)");
    tft.setRotation(3);
    tft.setTextColor(ILI9341_WHITE);
    tft.setTextDatum(MR_DATUM); // Middle right text datum
    tft.drawNumber((((graph_scale_ymin)*y_zoom)/4095), gr.getPointX(graph_scale_xmin), gr.getPointY(graph_scale_ymin));
    tft.drawNumber(0, gr.getPointX(graph_scale_xmin), gr.getPointY(graph_scale_ymax - graph_scale_ymin));
    tft.drawNumber((((graph_scale_ymax)*y_zoom)/4095), gr.getPointX(graph_scale_xmin), gr.getPointY(graph_scale_ymax));

  }
 
  if (micros() - plotTime >= 1) { //edited from sampletime
    plotTime = micros();


    // Add a new point on each trace
    //tr1.addPoint(gx, gy);
    real_data[int(gx)] = gy;
    //Serial.println(real_data[int(gx)]);
    display_data[int(gx)] = real_data[int(gx)]*(4095/y_zoom);
    tr2.addPoint(gx, gy);
    //tr2.addPoint(gx, gy/2.0); // half y amplitude


    // Create next plot point
    gx += 1.0;
    //gy += delta;
    ADC_14bit_val = 0;
    ADC_14bit_val = (ADC1_valH<<8 | ADC1_valL)>>4;
    gy = ((((ADC_14bit_val*5)/16383)-2.5)*2) ;//+= delta;
    //if (gy >  70.0) { delta = -7.0; gy =  70.0; }
    //if (gy < -70.0) { delta =  7.0; gy = -70.0; }


    // If the end of the graph is reached start 2 new traces
    if (gx > 100) {
      gx = 0.0;
      gy = display_data[99];


      // Draw empty graph at 40,10 on display
      gr.drawGraph(graph_top_corner_x, graph_top_corner_y);
   
      // Start new trace
      //tr1.startTrace(TFT_GREEN);
      tr2.startTrace(TFT_YELLOW);
    }
   
  }
}
}    


//*****************************************************
// Functions
//*****************************************************


void pauseTFTComms(){
  digitalWrite(screen_CS, HIGH);
  tft.endWrite();
}


void startTFTComms(){
  tft.startWrite();
  digitalWrite(screen_CS, LOW);
}

void ADC_Set_Default(){
  pauseTFTComms();
  delayMicroseconds(1);
  //digitalWrite(screen_CS, HIGH);
  SPI.beginTransaction(SPISettings(spi_max_clk, MSBFIRST, SPI_MODE3));// Mode 3 means clock is idle at HIGH and output edge is falling. Max SPI clk frequency is 50MHz.
  digitalWrite(ADC1_CS_pin, LOW);
  delayMicroseconds(1);
  SPI.transfer(0b1111); //sets converter to default mode
  delayMicroseconds(1);
  digitalWrite(ADC1_CS_pin, HIGH);
  digitalWrite(ADC1_CONVST_pin, HIGH);
  SPI.endTransaction();
  //digitalWrite(screen_CS, LOW);
  startTFTComms();
  return;


}


void ADC_collect_data(){
  pauseTFTComms();
  delayMicroseconds(1);
  //digitalWrite(screen_CS, HIGH);
  SPI.beginTransaction(SPISettings(spi_max_clk, MSBFIRST, SPI_MODE3));// Mode 3 means clock is idle at HIGH and output edge is falling. Max SPI clk frequency is 50MHz.
  digitalWrite(ADC1_CS_pin, LOW);
  delayMicroseconds(1); //delay 1ms
  //do {
    //int i = micros();
  //}while(!ADC1_EocInt);
  //int x = digitalRead(SDO_pin); //communicate with chip to get value
  ADC1_valH = SPI.transfer(0);
  delayMicroseconds(14);
  ADC1_valL = SPI.transfer(0);
  delayMicroseconds(14);
  digitalWrite(ADC1_CS_pin, HIGH);
  digitalWrite(ADC1_CONVST_pin, HIGH);
  SPI.endTransaction();
  //digitalWrite(screen_CS, LOW);
  startTFTComms();
  return ;


}






void trigger_set(){
  trigger_state = !trigger_state;
  return;
}


void trigger_function(){
  bool trigger_met = 0;
  while(!trigger_met){
    static uint32_t plotTime_tgr = micros(); // used to be = millis(), now using micros
    for (int i = 0; i<6;i++){
      if (micros() - plotTime_tgr >= 1) { //edited from sampletime
        plotTime_tgr = micros();
        ADC_14bit_val = (ADC1_valH<<8 | ADC1_valL)>>4;
        int val_tgr = ((((ADC_14bit_val*5)/16383)-2.5)*2) ;
        int y_zoom_tgr = analogRead(ampScale_wiper) + 1;//analogRead(36) + 1; // GPIO 36
        trigger_data[i] = val_tgr;
    }
  
  if (trigger_state){                                         // rising edge trigger logic
      int i = 0;
      if (trigger_data[i]<=trigger_data[i+1]){
        if(trigger_data[i+1]<=trigger_data[i+2]){
          if(trigger_data[i+2]<=trigger_data[i+3]){
            if(trigger_data[i+3]<=trigger_data[i+4]){
                trigger_met=1;


            }


          }


        }
      }


    } else {
      int j = 0;
      if (trigger_data[j]>=trigger_data[j+1]){
        if(trigger_data[j+1]>=trigger_data[j+2]){
          if(trigger_data[j+2]>=trigger_data[j+3]){
            if(trigger_data[j+3]>=trigger_data[j+4]){
              trigger_met = 1;
              }


            }


          }


        }
      }


    }
  
  }
  
  return;

}

  

/*
  static uint32_t plotTime_tgr = micros(); // used to be = millis(), now using micros
  for (int i = 0; i<50;i++){
    if (micros() - plotTime_tgr >= 10) { //edited from sampletime
      plotTime_tgr = micros();
      int val_tgr = analogRead(35);
      int y_zoom_tgr = 4095;//analogRead(36) + 1; // GPIO 36
      static float gy_tgr = ((val_tgr/41)-50)*(4095/y_zoom_tgr);
      trigger_data[i] = gy_tgr;
    }  
  }
  if (trigger_state){                                         // rising edge trigger logic
    for (int i = 0; i<50;i++){
      if (trigger_data[i]<=trigger_data[i+1]){
        if(trigger_data[i+1]<=trigger_data[i+2]){
          if(trigger_data[i+2]<=trigger_data[i+3]){
            if(trigger_data[i+3]<=trigger_data[i+4]){
              for (int j = i; j < 100; j++){
                display_data[i] = trigger_data[i];
              }


            }


          }


        }
      }


    }
  } else {
    for (int i = 0; i<50;i++){
      if (trigger_data[i]>=trigger_data[i+1]){
        if(trigger_data[i+1]>=trigger_data[i+2]){
          if(trigger_data[i+2]>=trigger_data[i+3]){
            if(trigger_data[i+3]>=trigger_data[i+4]){
              for (int j = i; j < 50; j++){
                display_data[i] = trigger_data[i];
              }


            }


          }


        }
      }


    }
  }


 
  return;
}
*/

void pause_button(){
  pause_state = !pause_state;
  return;
}






int findMax(float array[]){
  int max = array[0];
  for (int i=1; i < 100; i++){
    if (array[i] > max){
      max = array[i];
    }


  }
  return max;
}


int findMin(float array[]){
  int min = array[0];
  for (int i=1; i < 100; i++){
    if (array[i] < min){
      min = array[i];
    }


  }
  return min;
}




unsigned long testFillScreen() {
  unsigned long start = micros();
  tft.fillScreen(ILI9341_BLACK);
  tft.fillScreen(ILI9341_RED);
  tft.fillScreen(ILI9341_GREEN);
  tft.fillScreen(ILI9341_BLUE);
  tft.fillScreen(ILI9341_BLACK);
  return micros() - start;
}
 
unsigned long testText() {
  tft.fillScreen(ILI9341_BLACK);
  unsigned long start = micros();
  tft.setCursor(0, 0);
  tft.setTextColor(ILI9341_WHITE);  tft.setTextSize(1);
  tft.println("Hello World!");
  tft.setTextColor(ILI9341_YELLOW); tft.setTextSize(2);
  tft.println(1234.56);
  tft.setTextColor(ILI9341_RED);    tft.setTextSize(3);
  tft.println(0xDEADBEEF, HEX);
  tft.println();
  tft.setTextColor(ILI9341_GREEN);
  tft.setTextSize(5);
  tft.println("Groop");
  tft.setTextSize(2);
  tft.println("I implore thee,");
  tft.setTextSize(1);
  tft.println("my foonting turlingdromes.");
  tft.println("And hooptiously drangle me");
  tft.println("with crinkly bindlewurdles,");
  tft.println("Or I will rend thee");
  tft.println("in the gobberwarts");
  tft.println("with my blurglecruncheon,");
  tft.println("see if I don't!");
  return micros() - start;
}
 
unsigned long testLines(uint16_t color) {
  unsigned long start, t;
  int           x1, y1, x2, y2,
                w = tft.width(),
                h = tft.height();
 
  tft.fillScreen(ILI9341_BLACK);
 
  x1 = y1 = 0;
  y2    = h - 1;
  start = micros();
  for(x2=0; x2<w; x2+=6) tft.drawLine(x1, y1, x2, y2, color);
  x2    = w - 1;
  for(y2=0; y2<h; y2+=6) tft.drawLine(x1, y1, x2, y2, color);
  t     = micros() - start; // fillScreen doesn't count against timing
 
  tft.fillScreen(ILI9341_BLACK);
 
  x1    = w - 1;
  y1    = 0;
  y2    = h - 1;
  start = micros();
  for(x2=0; x2<w; x2+=6) tft.drawLine(x1, y1, x2, y2, color);
  x2    = 0;
  for(y2=0; y2<h; y2+=6) tft.drawLine(x1, y1, x2, y2, color);
  t    += micros() - start;
 
  tft.fillScreen(ILI9341_BLACK);
 
  x1    = 0;
  y1    = h - 1;
  y2    = 0;
  start = micros();
  for(x2=0; x2<w; x2+=6) tft.drawLine(x1, y1, x2, y2, color);
  x2    = w - 1;
  for(y2=0; y2<h; y2+=6) tft.drawLine(x1, y1, x2, y2, color);
  t    += micros() - start;
 
  tft.fillScreen(ILI9341_BLACK);
 
  x1    = w - 1;
  y1    = h - 1;
  y2    = 0;
  start = micros();
  for(x2=0; x2<w; x2+=6) tft.drawLine(x1, y1, x2, y2, color);
  x2    = 0;
  for(y2=0; y2<h; y2+=6) tft.drawLine(x1, y1, x2, y2, color);
 
  return micros() - start;
}
 
unsigned long testFastLines(uint16_t color1, uint16_t color2) {
  unsigned long start;
  int           x, y, w = tft.width(), h = tft.height();
 
  tft.fillScreen(ILI9341_BLACK);
  start = micros();
  for(y=0; y<h; y+=5) tft.drawFastHLine(0, y, w, color1);
  for(x=0; x<w; x+=5) tft.drawFastVLine(x, 0, h, color2);
 
  return micros() - start;
}
 
unsigned long testRects(uint16_t color) {
  unsigned long start;
  int           n, i, i2,
                cx = tft.width()  / 2,
                cy = tft.height() / 2;
 
  tft.fillScreen(ILI9341_BLACK);
  n     = min(tft.width(), tft.height());
  start = micros();
  for(i=2; i<n; i+=6) {
    i2 = i / 2;
    tft.drawRect(cx-i2, cy-i2, i, i, color);
  }
 
  return micros() - start;
}
 
unsigned long testFilledRects(uint16_t color1, uint16_t color2) {
  unsigned long start, t = 0;
  int           n, i, i2,
                cx = tft.width()  / 2 - 1,
                cy = tft.height() / 2 - 1;
 
  tft.fillScreen(ILI9341_BLACK);
  n = min(tft.width(), tft.height());
  for(i=n; i>0; i-=6) {
    i2    = i / 2;
    start = micros();
    tft.fillRect(cx-i2, cy-i2, i, i, color1);
    t    += micros() - start;
    // Outlines are not included in timing results
    tft.drawRect(cx-i2, cy-i2, i, i, color2);
  }
 
  return t;
}
 
unsigned long testFilledCircles(uint8_t radius, uint16_t color) {
  unsigned long start;
  int x, y, w = tft.width(), h = tft.height(), r2 = radius * 2;
 
  tft.fillScreen(ILI9341_BLACK);
  start = micros();
  for(x=radius; x<w; x+=r2) {
    for(y=radius; y<h; y+=r2) {
      tft.fillCircle(x, y, radius, color);
    }
  }
 
  return micros() - start;
}
 
unsigned long testCircles(uint8_t radius, uint16_t color) {
  unsigned long start;
  int           x, y, r2 = radius * 2,
                w = tft.width()  + radius,
                h = tft.height() + radius;
 
  // Screen is not cleared for this one -- this is
  // intentional and does not affect the reported time.
  start = micros();
  for(x=0; x<w; x+=r2) {
    for(y=0; y<h; y+=r2) {
      tft.drawCircle(x, y, radius, color);
    }
  }
 
  return micros() - start;
}
 
unsigned long testTriangles() {
  unsigned long start;
  int           n, i, cx = tft.width()  / 2 - 1,
                      cy = tft.height() / 2 - 1;
 
  tft.fillScreen(ILI9341_BLACK);
  n     = min(cx, cy);
  start = micros();
  for(i=0; i<n; i+=5) {
    tft.drawTriangle(
      cx    , cy - i, // peak
      cx - i, cy + i, // bottom left
      cx + i, cy + i, // bottom right
      tft.color565(0, 0, i));
  }
 
  return micros() - start;
}
 
unsigned long testFilledTriangles() {
  unsigned long start, t = 0;
  int           i, cx = tft.width()  / 2 - 1,
                   cy = tft.height() / 2 - 1;
 
  tft.fillScreen(ILI9341_BLACK);
  start = micros();
  for(i=min(cx,cy); i>10; i-=5) {
    start = micros();
    tft.fillTriangle(cx, cy - i, cx - i, cy + i, cx + i, cy + i,
      tft.color565(0, i, i));
    t += micros() - start;
    tft.drawTriangle(cx, cy - i, cx - i, cy + i, cx + i, cy + i,
      tft.color565(i, i, 0));
  }
 
  return t;
}
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

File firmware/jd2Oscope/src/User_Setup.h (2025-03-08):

#ifndef _USER_SETUP_H_
#define _USER_SETUP_H_

//=============================================================================
// 1. Display Driver Selection
//-----------------------------------------------------------------------------

// Select the driver for the ILI9341 display:
#define ILI9341_DRIVER

//=============================================================================
// 2. SPI Bus Pin Definitions
//-----------------------------------------------------------------------------

// These pins are for the hardware SPI (VSPI) on the ESP32:
#define TFT_MOSI  23   // VSPI MOSI
#define TFT_MISO  19   // VSPI MISO
#define TFT_SCLK  18   // VSPI Clock

//=============================================================================
// 3. Display (ILI9341) Control Pin Definitions
//-----------------------------------------------------------------------------

// Assign the pins for the display module as follows:
#define TFT_CS    5    // Chip Select (screen_CS) -> GPIO 5
#define TFT_DC    4    // Data/Command control (screen_D/C) -> GPIO 4

// For many modules the reset pin is controlled internally or tied to 3.3V.
// If your module does not require an external reset control, set it to -1:
#define TFT_RST   -1   // Reset pin (-1 if not used)

//=============================================================================
// 4. SPI Frequency Setting
//-----------------------------------------------------------------------------

// Define the SPI clock frequency for the display.
// 40 MHz is typical for ILI9341 displays.
#define SPI_FREQUENCY  27000000

//=============================================================================
// 5. Touch Support & Touch Pins
//-----------------------------------------------------------------------------

#define TOUCH_CS           15  // Touchscreen chip select
#define TOUCH_IRQ          25  // IRQ pin
#define SPI_TOUCH_FREQUENCY 2700000


// ##################################################################################
//
// Section 3. Define the fonts that are to be used here
//
// ##################################################################################

// Comment out the #defines below with // to stop that font being loaded
// The ESP8366 and ESP32 have plenty of memory so commenting out fonts is not
// normally necessary. If all fonts are loaded the extra FLASH space required is
// about 17Kbytes. To save FLASH space only enable the fonts you need!

#define LOAD_GLCD   // Font 1. Original Adafruit 8 pixel font needs ~1820 bytes in FLASH
//#define LOAD_FONT2  // Font 2. Small 16 pixel high font, needs ~3534 bytes in FLASH, 96 characters
//#define LOAD_FONT4  // Font 4. Medium 26 pixel high font, needs ~5848 bytes in FLASH, 96 characters
//#define LOAD_FONT6  // Font 6. Large 48 pixel font, needs ~2666 bytes in FLASH, only characters 1234567890:-.apm
//#define LOAD_FONT7  // Font 7. 7 segment 48 pixel font, needs ~2438 bytes in FLASH, only characters 1234567890:-.
//#define LOAD_FONT8  // Font 8. Large 75 pixel font needs ~3256 bytes in FLASH, only characters 1234567890:-.
//#define LOAD_FONT8N // Font 8. Alternative to Font 8 above, slightly narrower, so 3 digits fit a 160 pixel TFT
//#define LOAD_GFXFF  // FreeFonts. Include access to the 48 Adafruit_GFX free fonts FF1 to FF48 and custom fonts

// Comment out the #define below to stop the SPIFFS filing system and smooth font code being loaded
// this will save ~20kbytes of FLASH
//#define SMOOTH_FONT

#endif  // _USER_SETUP_H_

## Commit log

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2025-01-23 block diagrams
    [ESP32.kicad_sch, ProbeInputs.kicad_sch, UserInteractionInterface.kicad_sch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]
2025-01-28 feat: kicad board dev
    parts added, general framework established
    [3362P-1-103LF.step, 5227161-2.step, ADCModule.kicad_sch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]
2025-01-28 ADC KiCAD
    [JD342 ADC.kicad_pcb, JD342 ADC.kicad_sch]
2025-01-29 fix: relative file paths
    added relative file paths for symbols & footprints such that everyone can access them on any machine they clone to
2025-01-29 feat: opAmpCircuit cleanup
    [ADCModule.kicad_sch, ADS7279IPW.STEP, JD342 ADC.kicad_sch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]
2025-01-29 feat: more reorganizing of adc
    [JD342 ADC.kicad_sch]
2025-01-29 feat: small tweaks to adc schematic structure
    [JD342 ADC.kicad_sch]
2025-01-29 fix: adc schematic structure v3
    small tweak; likely the last thing for now
    [JD342 ADC.kicad_sch]
2025-01-30 fix: pushing so people can edit!! (I think)
    [ESP32.kicad_sch, jd2oscope.kicad_sch]
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2025-02-14 added ADC 2
    [JD342 ADC 2.kicad_sch]
2025-02-15 feat: signals processing module
    added
    [SignalProcessingModule.kicad_sch]
2025-02-15 fix: JD342 ADC now opens properly
    there was an issue with having two kicad_sch files in the directory; replaced the old one w/ the new one & was able to fix it & thereafter view successfully
    [JD342 ADC 2.kicad_sch, JD342 ADC.kicad_sch]
2025-02-19 feat: screen implemented
    alongside screen implementation, re-structured layout for schematics, and cleaned up SPI comm. conn.s; also implemented ADC module successfully (sans SPI section for it; that comes next)
    [ADCModule.kicad_sch, ESP32.kicad_sch, PotentiometerModule.kicad_sch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]
2025-02-19 fix: gitignore to ignore kiCad backups
2025-02-19 feat: lot of progress
    added decoupling caps, implemented a lot more of the comm. protocol stuffs, updated BNC connector to updated version, added more notes for GPIO pin I/O for future code implementation, lot of other st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
    [5VRegulator.kicad_sch, ADCModule.kicad_sch, CONBNC001.step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]
2025-02-19 feat: more stuff added
    yep
    [ADCModule.kicad_sch, ESP32.kicad_sch, PotentiometerModule.kicad_sch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]
2025-02-19 feat: finished schematics
    I think! Subject to change tho! for now though at least, I think they look clean asf hah~
    [ADCModule.kicad_sch, PotentiometerModule.kicad_sch, buttonModule.kicad_sch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]
2025-02-19 fix: added NCs
    forgot to add NCs to Wroom32 dev board; they are now added!
    [PotentiometerModule.kicad_sch, jd2oscope.kicad_sch]
2025-02-20 fix: schematic page numbers
    they were out of order & weird, so I fixed them; should be good now! (there are 17 in total, let's go)
    [jd2oscope.kicad_sch, signalInterfaceModule.kicad_sch, signalInterfaces.kicad_sch]
2025-02-20 fix: added sym & ftprnt for esp32
    was using my local versions; added the actual sym and footprint files to the repo & changed library references to them so that everyone can access them too
2025-02-20 feat: added 3dModel STEP for esp32
    got it from snapEDA; still need to associate it with the footprint, however this is a good start
2025-02-20 fix: ERC funtimes
    fixed a bunch of dependencies with ERC checks for the schematic; shouuuuld be easier/actually possible to open on other devices now?? (added a buncha schematics & footprints to the local files & whatnot)
    [ADCModule.kicad_sch, PotentiometerModule.kicad_sch, Touchscreen_LCD_Display.kicad_sch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]
2025-02-20 fix: footprint/symbol fixes for ILI9341_Touch
    blegh
    [ADCModule.kicad_sch, PotentiometerModule.kicad_sch, Touchscreen_LCD_Display.kicad_sch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]
2025-02-20 feat: ERC is now happy!
    We now pass all ERC checks in terms of errors; it is now fully satisfied!! (and, any warnings are just due to the fact that we made local edits to global symbol values, so we're ballin' all the way frfr)
    [ADCModule.kicad_sch, Touchscreen_LCD_Display.kicad_sch, jd2oscope.kicad_sch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]
2025-02-20 feat/fix: no more errors for PCB import too!
    Now both the ERC, and the schematic import (and my OCD) are completely satisfied, and we can dev the actual PCB; let's go!! :D
    [ADCModule.kicad_sch, PotentiometerModule.kicad_sch, Touchscreen_LCD_Display.kicad_sch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]
2025-02-20 feat:net lists & net classes implemented
    labeled e/a net w/ net labels to clarify nodes, & created net classes w/ desired dimensions for traces; next up is assigning net classes to e/a net & using it to create the pcb!
    [ADCModule.kicad_sch, Touchscreen_LCD_Display.kicad_sch, jd2oscope.kicad_pcb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]
2025-02-20 feat: labeled net classes on root
    lolz
    [jd2oscope.kicad_sch]
2025-02-20 3d models
    3d models uploaded
    [Main Enclosure Bottom.step, Main Enclosure Cover.step]
2025-02-20 feat: Block 1 Testing
    Very early draft.
    [editorconfig.txt]
2025-02-20 feat: pcb progress
    [ADCModule.kicad_sch, jd2oscope.kicad_pcb, jd2oscope.kicad_sch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]
2025-02-21 feat: pcb complete
    ha gottem
    [OPA192IDBVR.STEP, RND 205-00001--3DModel-STEP-269445.STEP, jd2oscope.kicad_pcb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]
2025-02-21 feat: pcb 3d model
    exported pcb 3d model (hopefully looks good?)
    [jd2oscope.kicad_pcb]
2025-02-21 feat: noTracks PCB STEP too
    because the one with tracks was really big and I wanted to see if this smaller version would let me view it on github lol
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2025-02-21 fix: moved BOM to top level
    because it looks better there & not lost in the sea of kicad files it was otherwise in lol
2025-02-22 fix: M4 -> M3 & re-exported 3d models
    3d models now represent M3 board instead of M4 board (the mounting holes); I also added a cooler version with copper and vias, because well, it looks cooler (and also for "improved structural integrity) and whatnot when screwing stuffs in, too)
    [jd2oscope.kicad_pcb, jd2oscope_PCB_onlySMDs-noTracks.step]
2025-02-22 fix: arbitrary grammar thing in comment
    noticed a ) was missing from one of the text blocks in the schematic, so I added one :P
    [buttonModule.kicad_sch]
2025-02-22 feat: more 3d models stuffs
    woah
    [jd2oscope.kicad_pcb]
2025-02-22 feat: silkscreen updates
    note that DRC now produces warnings for some of the silkscreens on the back of the PCB. I am under the impression that they don't matter that much, & hoping it "just works"; if anything, minor bleed or inconsistencies in the text will be present (if silkscreen tolerances sabotage electrical continuity and the pcb doesn't work (*when they are close to no traces*), guess I deserved this one lol. But it SHOULD be fine!!)
    [bom.csv, designators.csv, jd2oscope.kicad_pcb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]
2025-02-23 fix: added change note
    note to change root labels to net class directives; will implement in the future, just wanted to put smth there so I remember to
    [jd2oscope.kicad_sch]
2025-02-23 fix: added another update note
    this time for how to properly represent the pin headers in the schematic; will update accordingly at a later date, just wanted to note something down in the meantime so I don't forget
    [jd2oscope.kicad_sch]
2025-02-25 new 3d prints
    [Bottom Print.step, Main Enclosure Bottom.step, Main Enclosure Cover.step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]
2025-02-25 replaced bottom and top print
    [Bottom Print.step, Top Print.step]
2025-02-27 feat: font tweaks
    nothing that big tbh
    [jd2oscope.kicad_sch]
2025-02-27 feat: filled in title block
    added relevant information to schematic title block blurb in the lower right
    [ADCModule.kicad_sch, PotentiometerModule.kicad_sch, Touchscreen_LCD_Display.kicad_sch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]
2025-02-27 fix: propagated group name to all sheets
    before it was just on the root; forgot to click the "apply to all sheets" textbox thingie
    [ADCModule.kicad_sch, PotentiometerModule.kicad_sch, Touchscreen_LCD_Display.kicad_sch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]
2025-03-01 feat: firmware testing scripts for esp32
    for block 2 checkoff; added in firmware section (not relevant to main oscilloscope's functionality)
2025-03-01 fix: schematic labels
    [ADCModule.kicad_sch, PotentiometerModule.kicad_sch, Touchscreen_LCD_Display.kicad_sch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]
2025-03-01 fix: undid the thing that I thought was a fix
    it is actually 12b still lol
    [ADCModule.kicad_sch, PotentiometerModule.kicad_sch, Touchscreen_LCD_Display.kicad_sch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]
2025-03-02 Start of Module 3- display settings
    Trying to get the display to work. All else has been commented out.
    [Front_End_controls.kicad_pcb, Front_End_controls.kicad_sch]
2025-03-02 fix: ILI9341 Library conflict
    To fix: switched to Bodmer's library instead; compiles on my end now. There was also a bunch of weird issues w/ the cache; those are good now too. Also added User_Setup.h; this is a req. of the Bodmer implementation; go there for all future pinout edits for ILI9341 in the scope of this project's implementation
    [pyvenv.cfg]
2025-03-06 Zoom with arduino timing
    Display with zoom, amplitude, and arduino timing. Only meant for prototyping so far.
2025-03-06 Prototype Display with pause
    Used interrupts on GPIO26 for pausing the screen. Paused screen looks hazy due to constantly updating the screen.
2025-03-06 Display with pause v2
    This version gets rid of the fuzzy pause screen but doesn't register for every button press (maybe because I'm using shaky jumper wires, maybe its the code)
    [main.cpp]
2025-03-06 Prototype Display with TRIGGER
    Trigger also implemented using interrupts. Trigger function collects the first 200 data points and sifts through them until it finds 5 consecutive rising or falling points, then displays the rest of 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
2025-03-06 Prototype code with trigger, zoom, Amplitude, and pause
    Edited to have less garbage pseudocode. Easier to read now.
2025-03-07 chore: updated 3d files
    added new enclosure files, updated naming schemes, added potentiometer knobs for voltage and time
    [Bottom Print.step, PCB_onlySMDs-noTracks.step, PotKnob_T-3x.step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]
2025-03-07 Updated neatness + trigger
    New trigger function allows for faster data collection(IDK why i thought collecting double the samples for every frame was a good idea
2025-03-07 feat: better BOM file
    looks pr cool ngl
2025-03-08 feat: note on important fix for screen function
    [jd2oscope.kicad_sch]
2025-03-08 feat: code updates
    general fixes
    [User_Setup.h, main.cpp]
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2025-03-08 Pin update with latest SPI attempt
    We're getting close to the goal...
2025-03-09 feat: testing files
    note: they do not really work atm
    [ADCModule.kicad_sch]
2025-03-09 fix: duplicate declarations
    condensed duplicate declarations; moved them all to Oscilloscope.h & fixed a few var types too
    [main.cpp]
2025-03-09 Latest version: bit banging spi attempt
    This version tries to use the bit banging approach as the arduino SPI library might not work with our setup.
    [main.cpp]
2025-03-10 feat: updated capacitor values
    and other fixes too
    [ADCModule.kicad_sch, Touchscreen_LCD_Display.kicad_sch, jd2oscope.kicad_sch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]
2025-03-10 chore: re-organizing files
    [Front_End_controls.kicad_pcb, Front_End_controls.kicad_sch, JD342 ADC.kicad_pcb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]
